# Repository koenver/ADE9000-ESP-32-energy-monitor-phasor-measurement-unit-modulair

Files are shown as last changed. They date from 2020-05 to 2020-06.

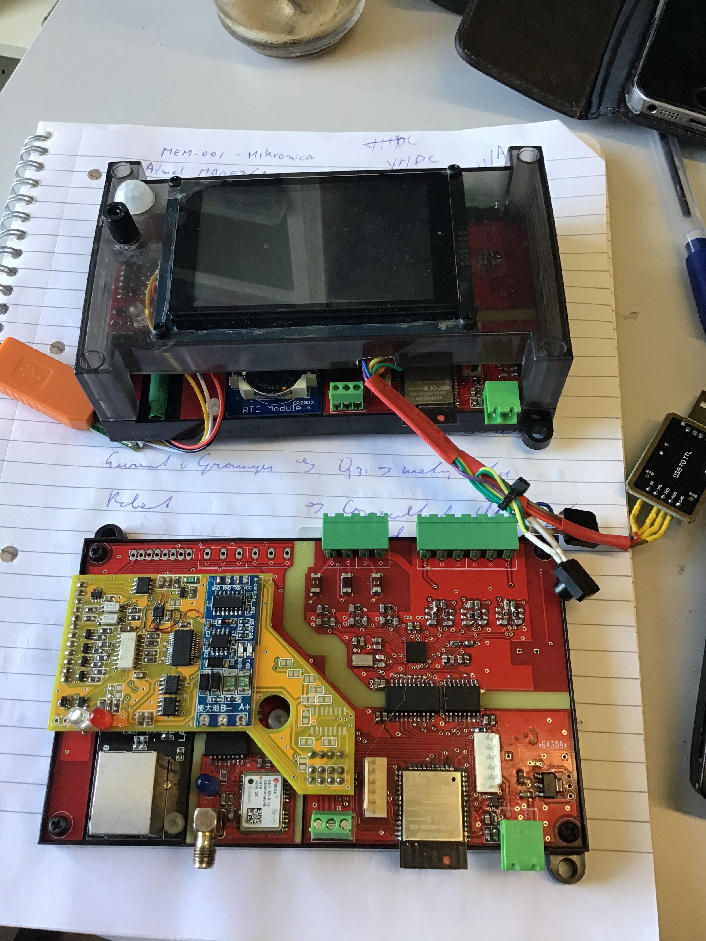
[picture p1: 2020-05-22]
hardware/pictures/IMG_0286.jpg

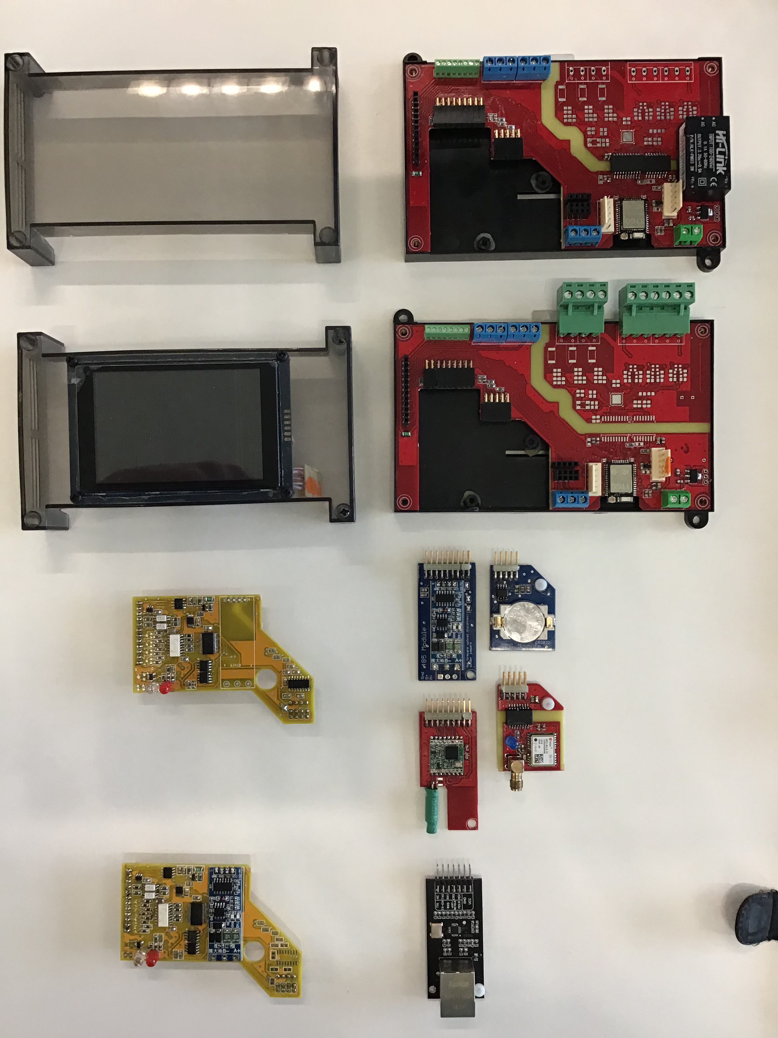
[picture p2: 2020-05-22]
hardware/pictures/IMG_0275.jpg

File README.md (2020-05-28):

# **ADE9000 ESP-32 energy-monitor / phasor-measurement-unit modulair**<br/>

*Prototype version of an Energy Measurement / Phasor Measurement unit with modulair interface modules*<br/>

**Specs:**<br/>
* ESP-32 processor (with double SPI and multicore, multi-tasking) and Wifi<br/> 
* Galvanic seperation with ADUM chips <br/>
* ADE9000 3 phase Energy Measurement IC , version for CT (5VA) or <br/>
        rogowski (0.1mV/A), 8kHz wavebuffering , harmonics analyses and <br/>
        event processing for 50Hz , 230V 3 phase Energy systems <br/>
* Module 1 slot: 485 interface / lorawan 868 Mhz/ Ethernet lan8720 (waveshare)<br/>
        
* Module 2 slot: Ublox GPS / DS3232 RTC<br/> 
* Expansion board: 485 interface, 2x 24lc512, mcp23017, ds2482, mcp4725,BME680<br/> 
        so 4 DI (opto), 4 DO (opto), 1-wire , temp, humidity, voc, air-pressure, <br/>
	AD en DA inputs and extra flash <br/>
* Optional I2C display  (SED1306 or H35B-I)<br/>
* future development:  security TLS1.3, module 2 with NB-Iot-LTE-M (Ublox)<br/> 
* Arduino IDE , in RTOS , C++ Language <br/>
<br/>

#### *Now in testing phase -> so only use parts which I confirmed status tested*<br/>
#### *better wait till new PCB's are published, instead of using the manual re-wiring*<br/>
*Software will be open source. (New) soft- and hardware which is based on this*<br/> 
*project and used by others, have the obligation of open source publishing*<br/> 
*at Github*<br/>

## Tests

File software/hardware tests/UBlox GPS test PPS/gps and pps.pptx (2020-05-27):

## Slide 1

PPS pulse of GPS: duration 100ms

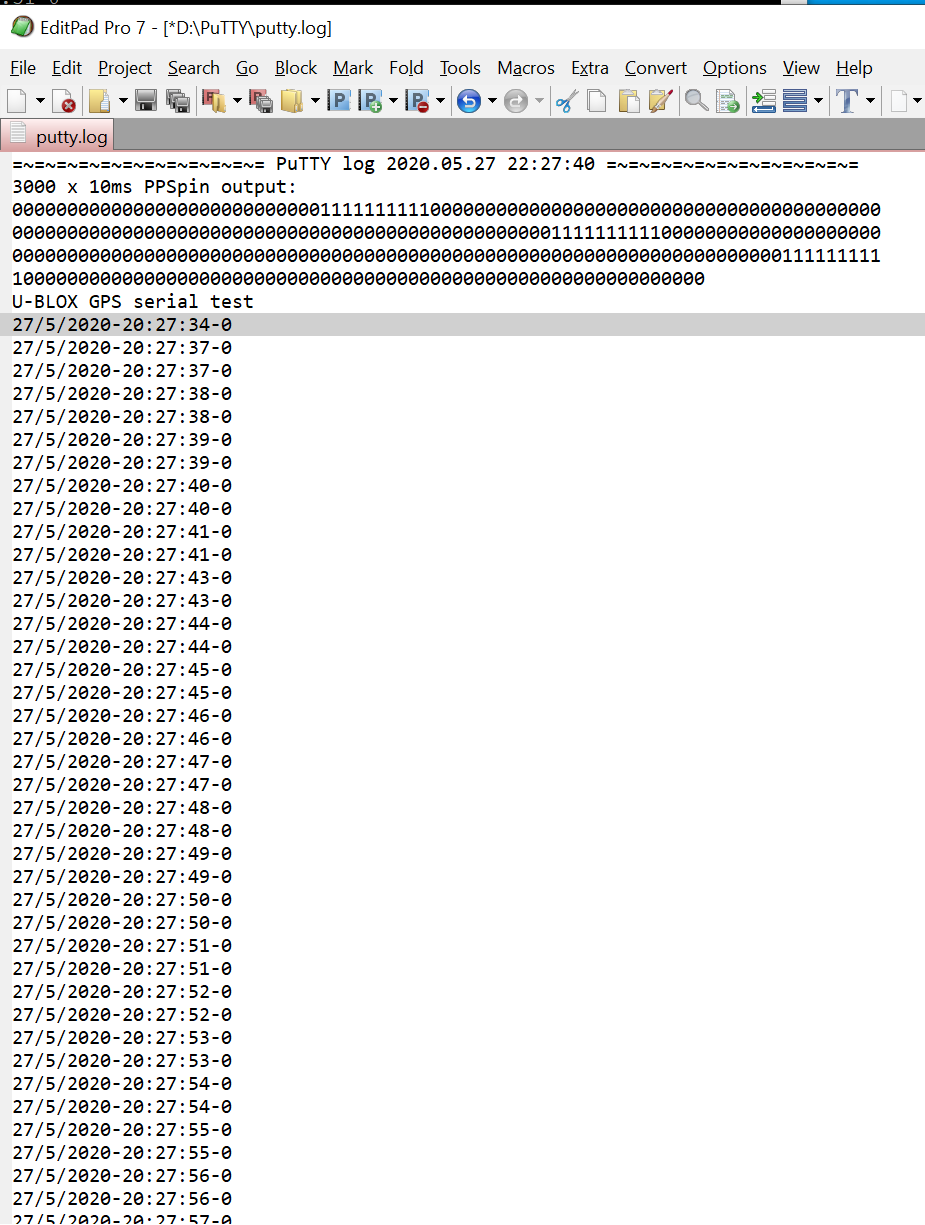
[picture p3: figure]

PPS of 100ms
is seen 10x10ms

Modification PCB :
gpio 9 and 10
aren’t free with DIO..
So Tx-GPS was placed at ESP-RX1 …GPS module needs to be removed before programming! ESP-TX was used for terminal debug (9600baud)
This gives the repeating error:
(putty at Tx and GPS at Rx)

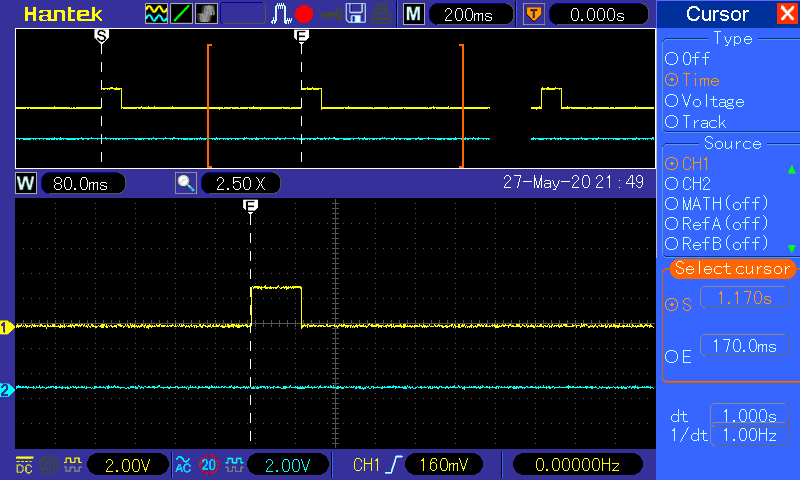
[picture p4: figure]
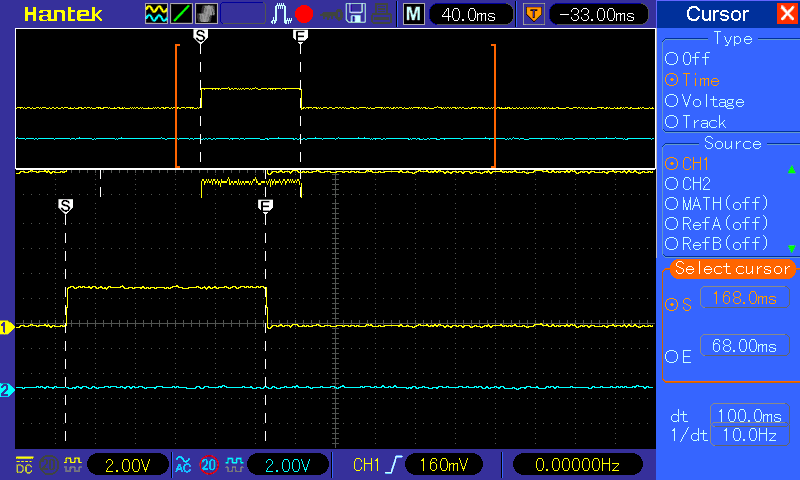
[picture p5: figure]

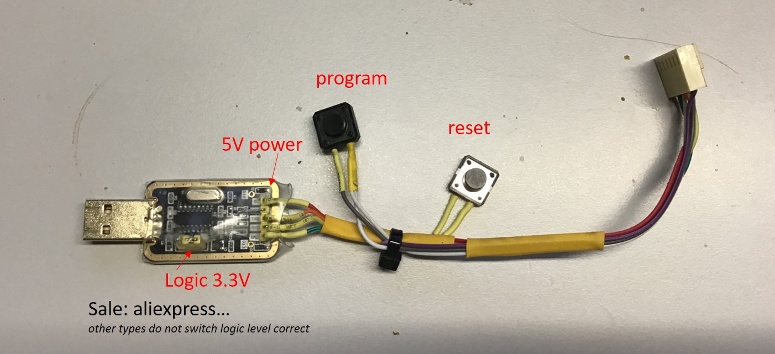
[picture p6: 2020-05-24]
software/hardware tests/programmer/programmer.jpg

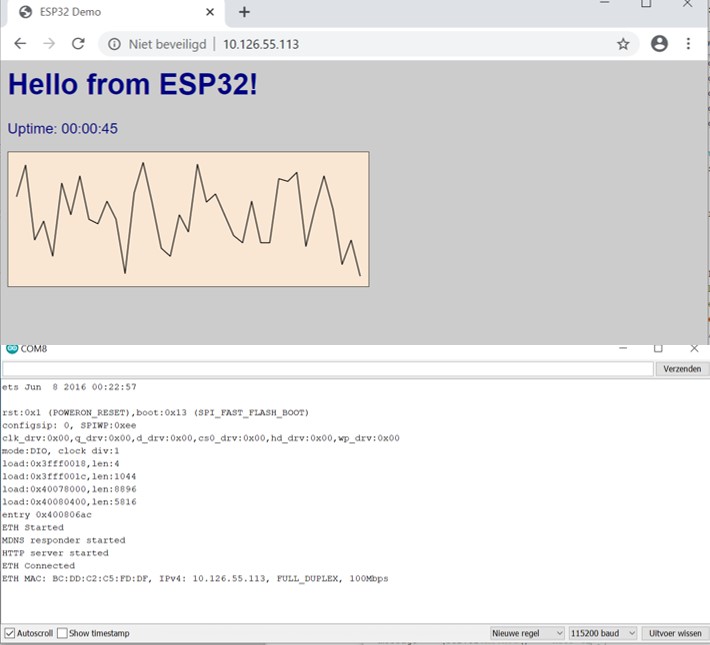
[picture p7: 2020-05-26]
software/hardware tests/lan8720 test/servertest-OK/ETH_LAN8720webserver-output.jpg

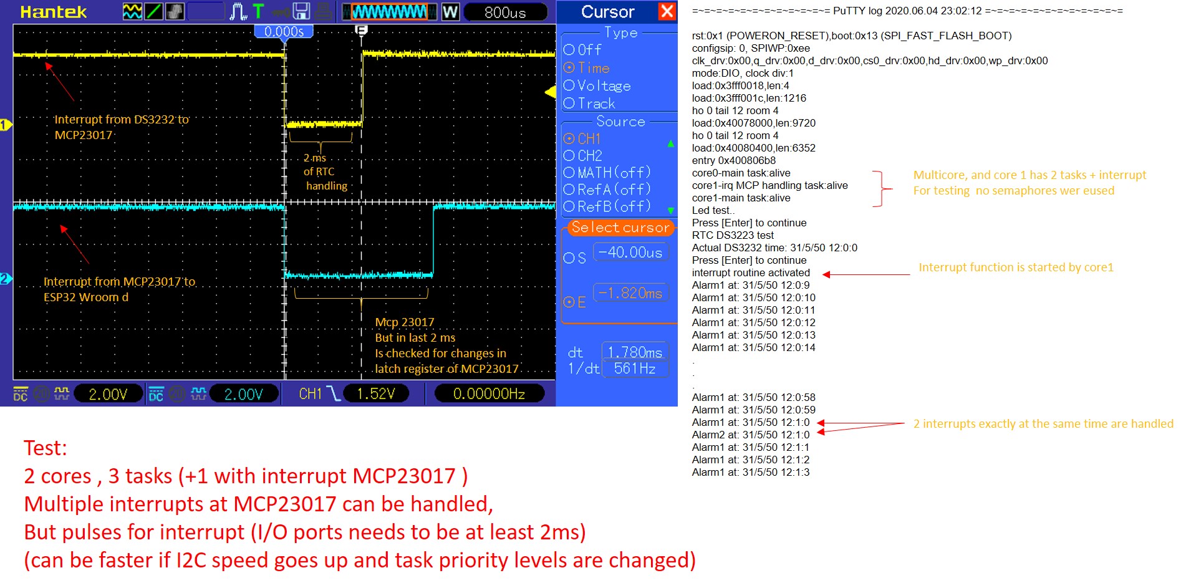
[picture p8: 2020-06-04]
software/hardware tests/MCP23017-IRQ-mCore-DS3232 test/MCP-multicore -interrupt.jpg

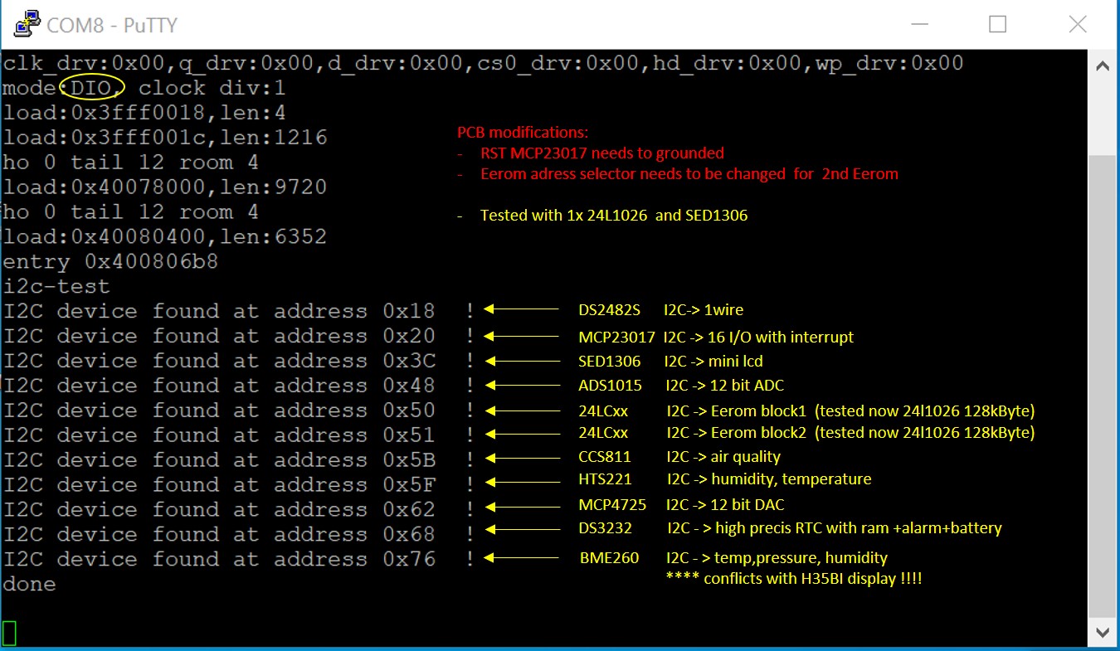
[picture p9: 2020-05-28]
software/hardware tests/i2c test/I2C adres dump1.jpg

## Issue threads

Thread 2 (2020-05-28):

RST of MCP23107 needs to be grounded (expansion board)

koenver, 2020-05-28:
resolved temp:  little wire soldered

koenver, 2020-06-04:
sorry..my mistake ..is an  "/RST"  so must be wired to 3.3V

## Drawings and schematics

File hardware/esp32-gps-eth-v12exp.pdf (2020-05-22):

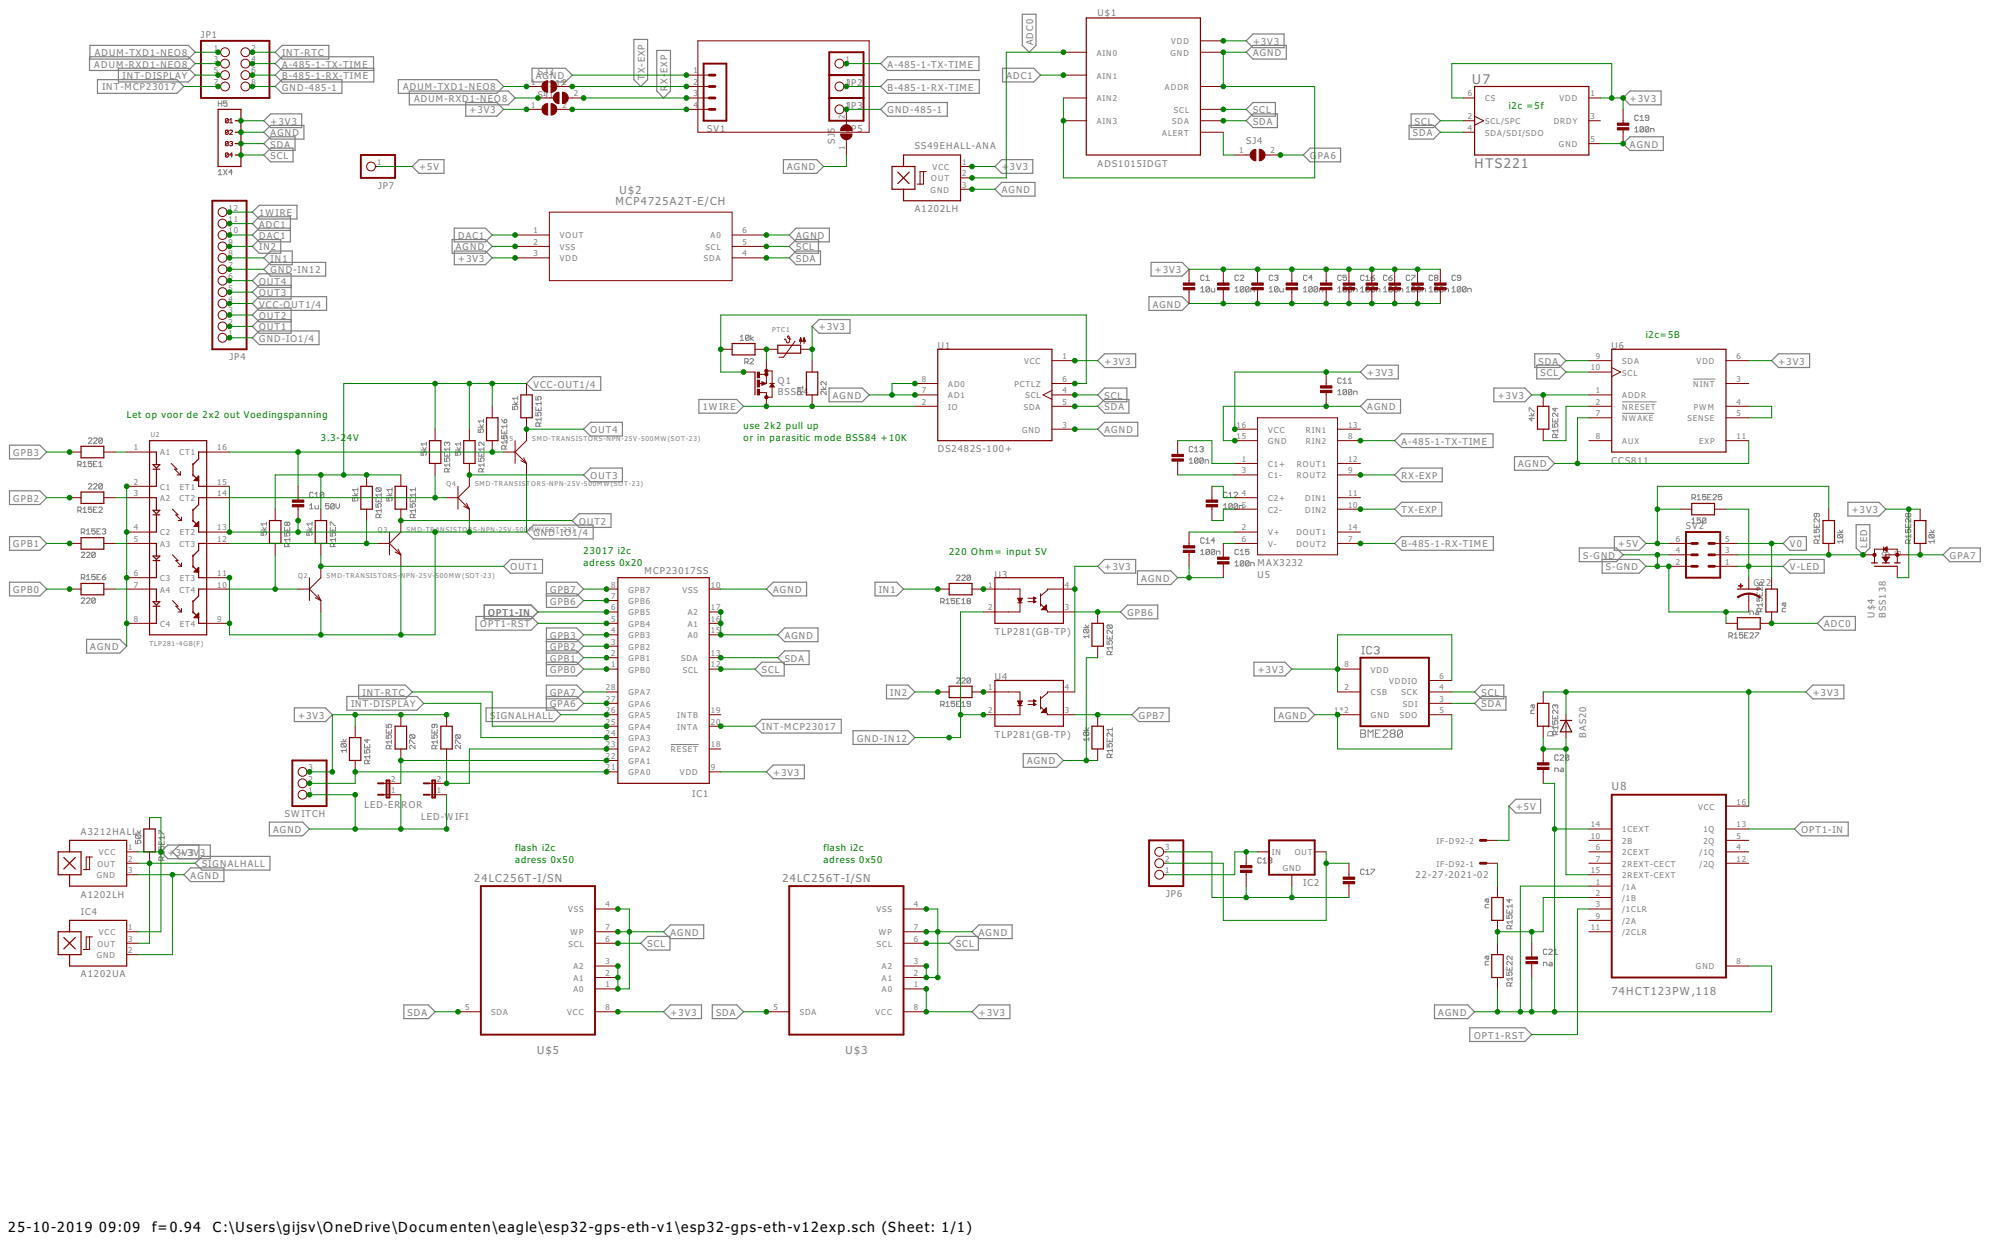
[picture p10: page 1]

Let op voor de 2x2 out Voedingspanning

SMD-TRANSISTORS-NPN-25V-500MW (SOT-23)

25-10-2019 09:09 f=0.94 C:\Users\gijsv\OneDrive\Documenten\eagle\esp32-gps-eth-v1\esp32-gps-eth-v12exp.sch (Sheet: 1/1)

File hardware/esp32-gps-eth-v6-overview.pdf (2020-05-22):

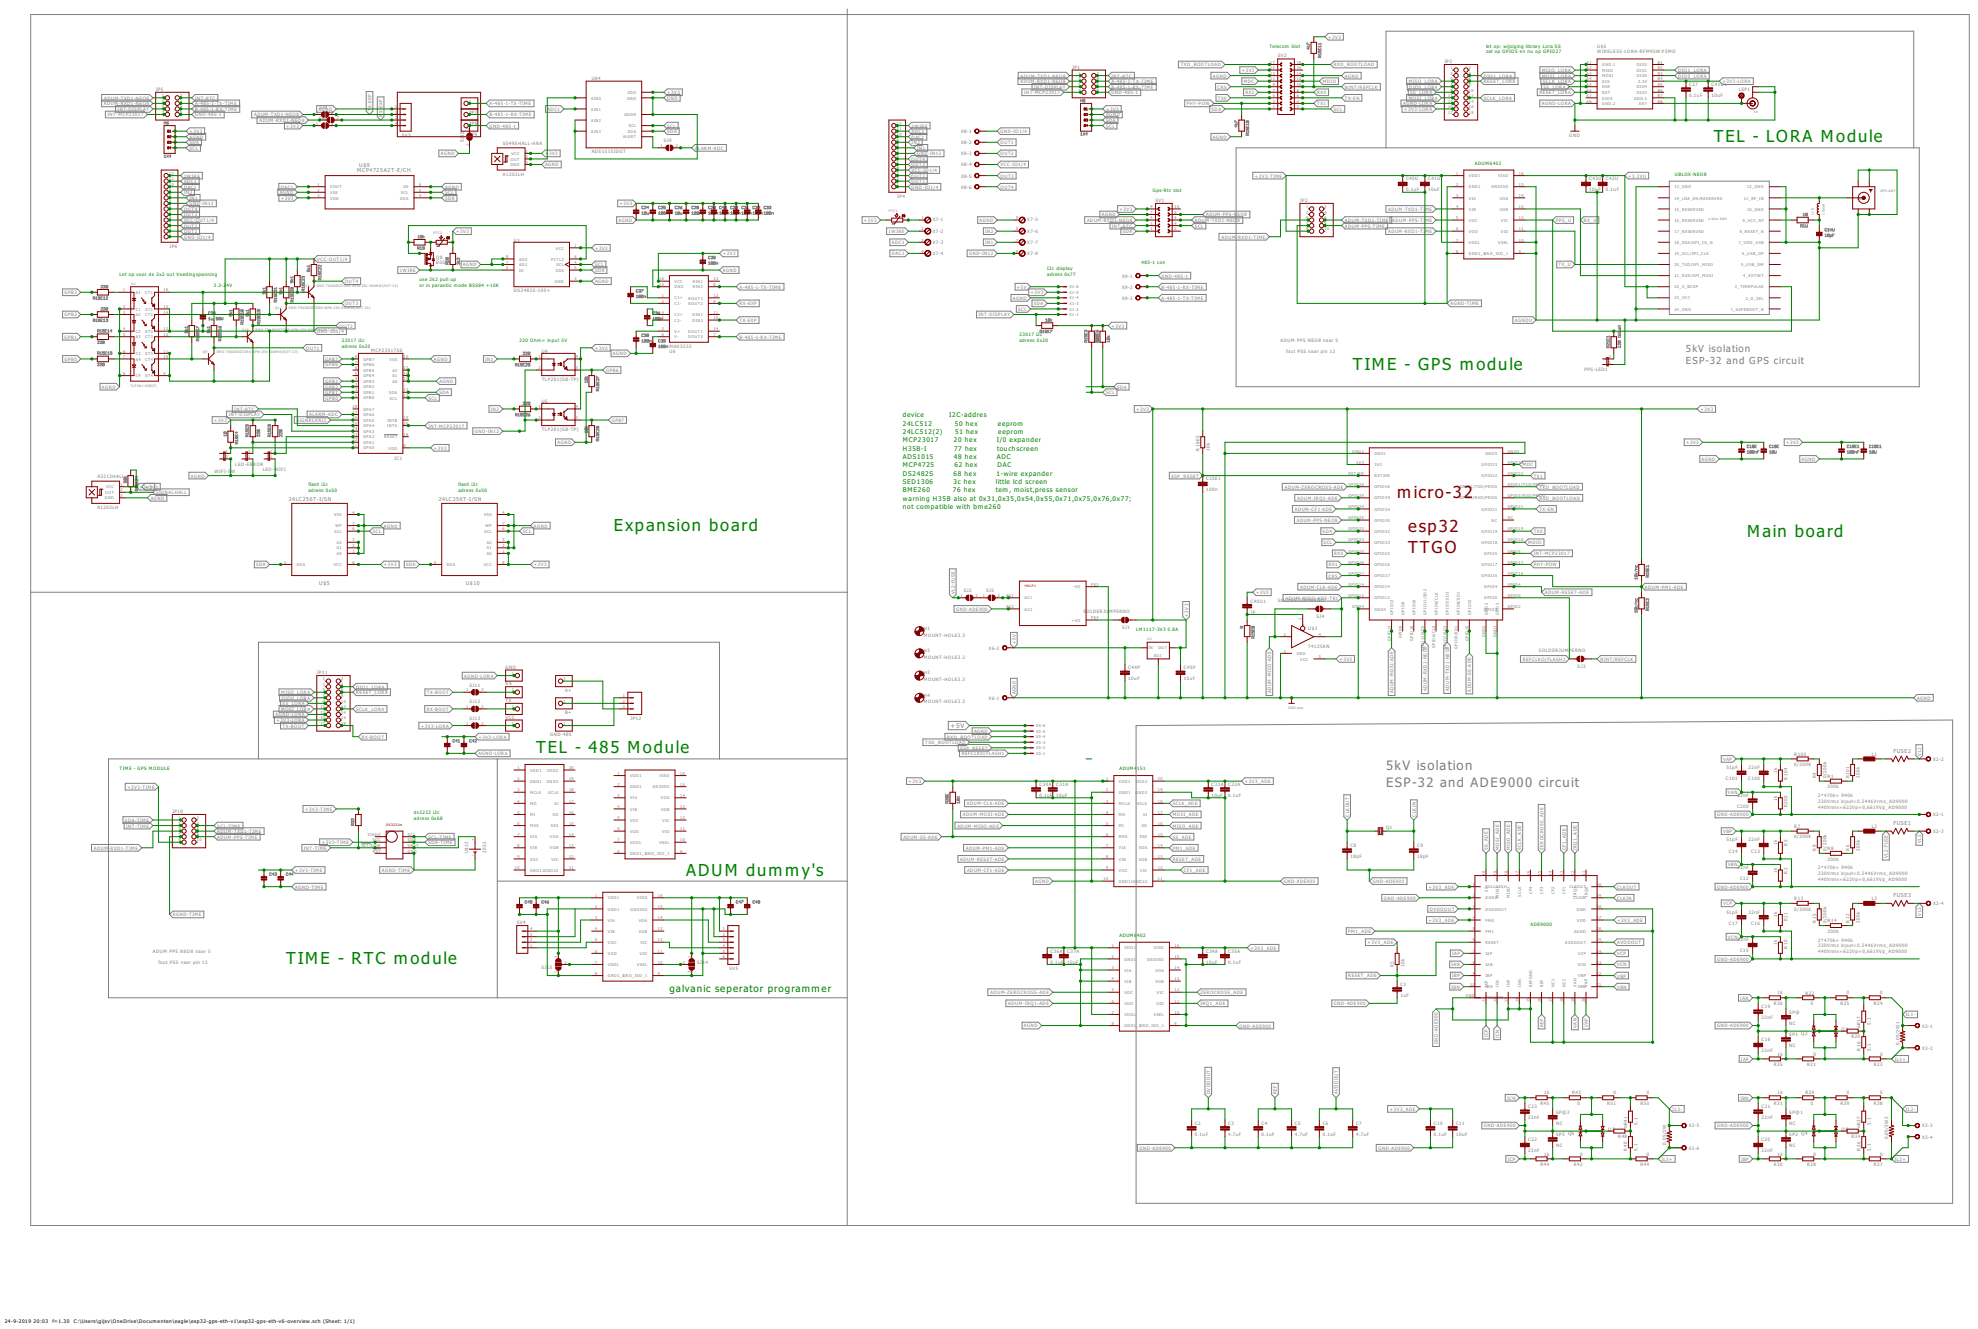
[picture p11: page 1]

let op: wijziging library Lora SS
zat op GPIO5 en nu op GPIO27

Let op voor de 2x2 out Voedingspanning

SMD-TRANSISTORS-NPN-25V-500MW (SOT-23)

5kV isolation
ESP-32 and GPS circuit

fout PSS naar pin 12

Main board Expansion board

ADUM-MISO-ADE-TRI
SOLDERJUMPERNO

SpiceOrder 1 SpiceOrder 2

24-9-2019 20:03 f=1.30 C:\Users\gijsv\OneDrive\Documenten\eagle\esp32-gps-eth-v1\esp32-gps-eth-v6-overview.sch (Sheet: 1/1)

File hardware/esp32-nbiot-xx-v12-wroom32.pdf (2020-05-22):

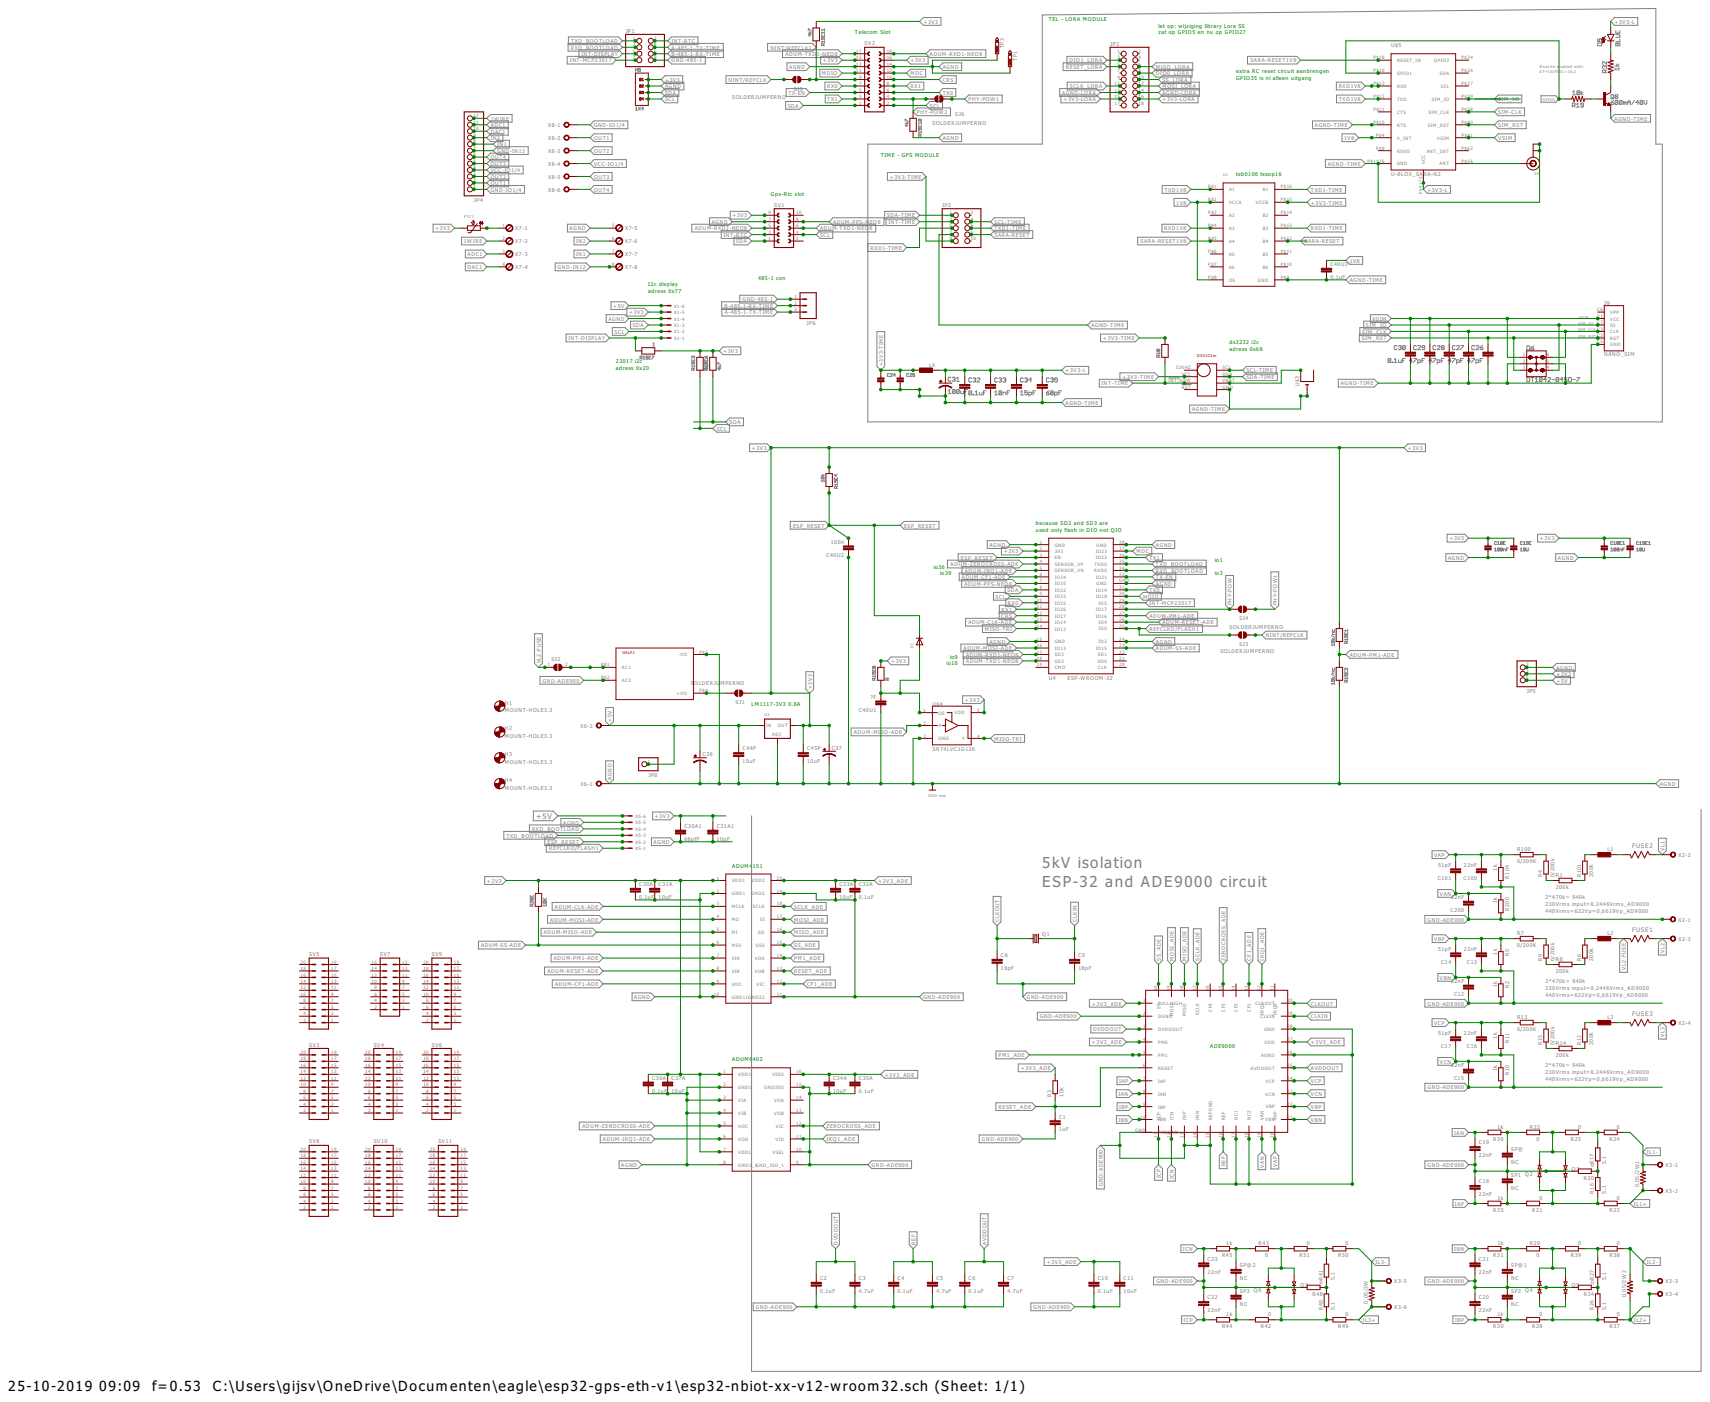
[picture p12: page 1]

zat op GPIO5 en nu op GPIO27 TEL - LORA MODULE

let op: wijziging library Lora SS

extra RC reset circuit aanbrengen GPIO35 is nl alleen uitgang

Must be enabled with: AT+UGPIOC=16,2

AGND-TIME AGND-TIME AGND-TIME

because SD2 and SD3 are used only flash in DIO not QIO

MOUNT-HOLE3.3 MOUNT-HOLE3.3

Sp ic eOrd er 1 Sp ic eOrd er 2

25-10-2019 09:09 f=0.53 C:\Users\gijsv\OneDrive\Documenten\eagle\esp32-gps-eth-v1\esp32-nbiot-xx-v12-wroom32.sch (Sheet: 1/1)

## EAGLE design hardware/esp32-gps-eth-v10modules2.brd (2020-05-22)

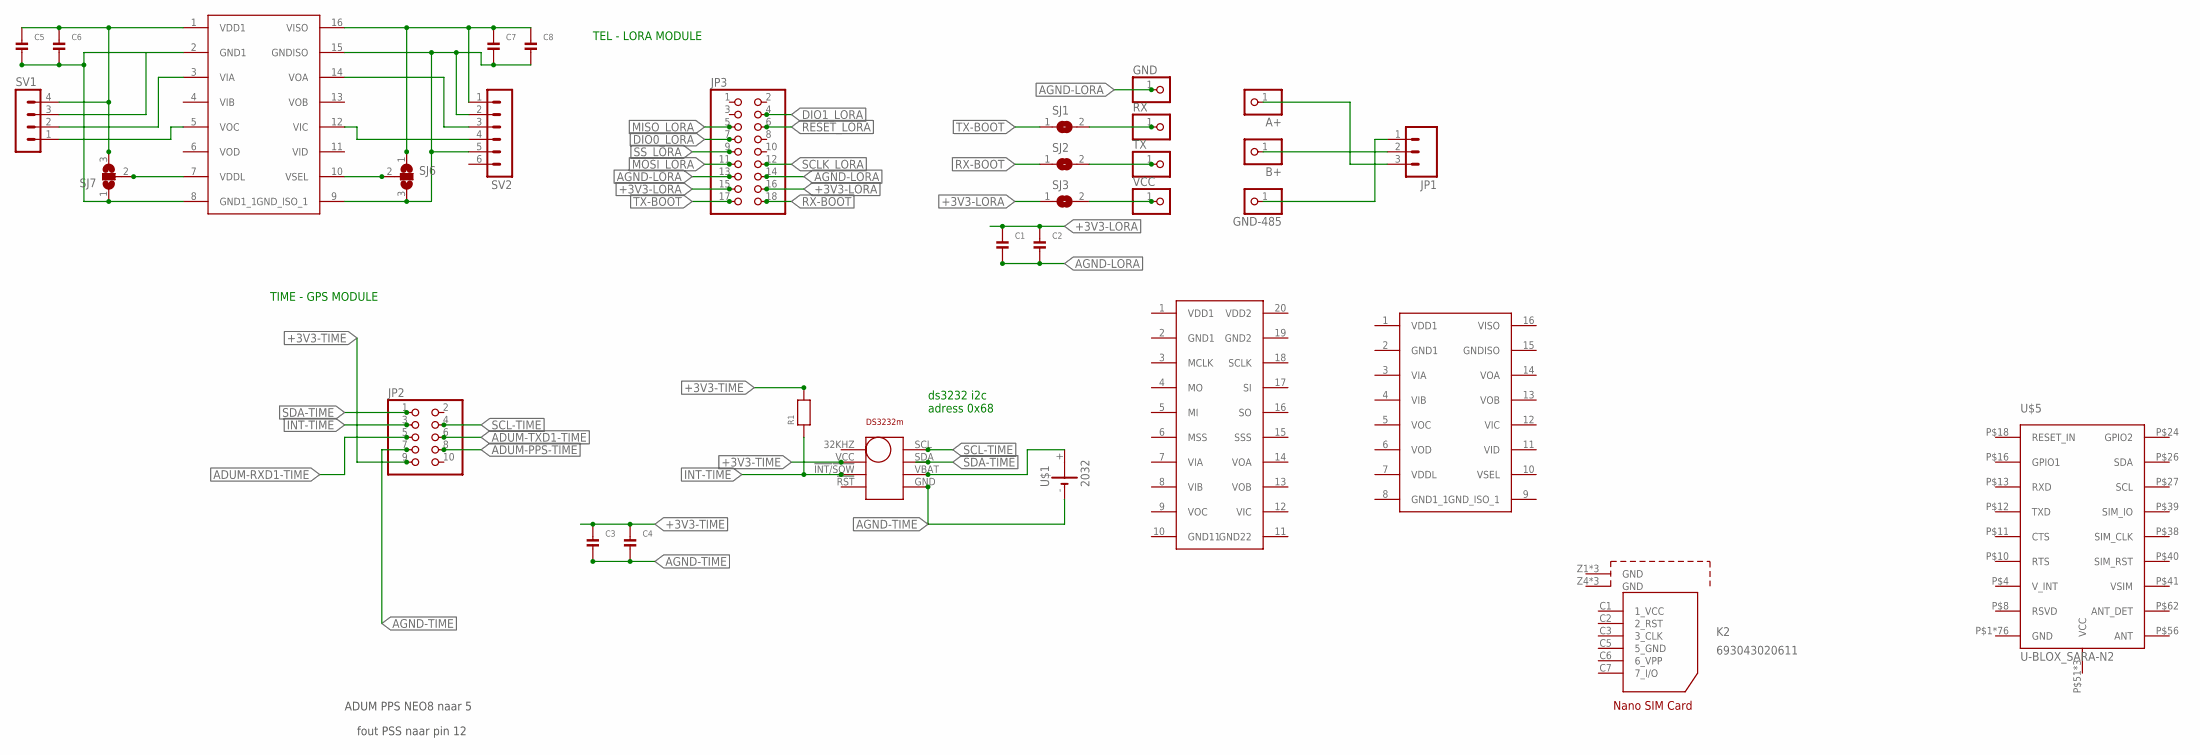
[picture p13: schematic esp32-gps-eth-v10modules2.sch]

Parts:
A+: PINHD-1X1CB; 1X01-CLEANBIG
ADUM4151: ADUM4151; SOIC20R
B+: PINHD-1X1CB; 1X01-CLEANBIG
C1, C2, C3, C4, C5, C6, C7, C8: CAP_CERAMIC0805; 0805
GND: PINHD-1X1CB; 1X01-CLEANBIG
GND-485: PINHD-1X1CB; 1X01-CLEANBIG
JP1: M03SCREW; SCREWTERMINAL-3.5MM-3
JP2: PINHD-2X5/90; 2X05/90
JP3: PINHD-2X9/90; 2X09/90
K2: 693043020611
R1: RESISTOR0805; 0805
RX: PINHD-1X1CB; 1X01-CLEANBIG
SJ1, SJ2, SJ3: SOLDERJUMPERREFLOW; SOLDERJUMPER_REFLOW
SJ6, SJ7: SJ2W; SJ_2
SV1: MA04-1
SV2: MA06-1
TX: PINHD-1X1CB; 1X01-CLEANBIG
U$1: 2032; KZH20SMD
U$2, U$3: ADUM6402; SOIC16R
U$4: DS3232M; SOIC8
U$5: U-BLOX_SARA-N2; SARA-N2
VCC: PINHD-1X1CB; 1X01-CLEANBIG

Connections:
+3V3-LORA: C1.1, C2.1, JP3.15, JP3.16, SJ3.1
+3V3-TIME: C3.1, C4.1, JP2.9, R1.2, U$4.VCC
ADUM-PPS-TIME: JP2.8
ADUM-RXD1-TIME: JP2.5
ADUM-TXD1-TIME: JP2.6
AGND-LORA: C1.2, C2.2, GND.1, JP3.13, JP3.14
AGND-TIME: C3.2, C4.2, JP2.7, U$1.-, U$4.GND
DIO0_LORA: JP3.7
DIO1_LORA: JP3.4
GND: U$5.P$1 (GND), U$5.P$2 (GND), U$5.P$3 (GND), U$5.P$5 (GND), U$5.P$6 (GND), U$5.P$7 (GND), U$5.P$9 (GND), U$5.P$14 (GND), U$5.P$15 (GND), U$5.P$17 (GND), U$5.P$19 (GND), U$5.P$20 (GND), U$5.P$21 (GND), U$5.P$22 (GND), U$5.P$23 (GND), U$5.P$25 (GND), U$5.P$28 (GND), U$5.P$29 (GND), U$5.P$30 (GND), U$5.P$31 (GND), U$5.P$32 (GND), U$5.P$33 (GND), U$5.P$34 (GND), U$5.P$35 (GND), U$5.P$36 (GND), U$5.P$37 (GND), U$5.P$42 (GND), U$5.P$43 (GND), U$5.P$44 (GND), U$5.P$45 (GND), U$5.P$46 (GND), U$5.P$47 (GND), U$5.P$48 (GND), U$5.P$49 (GND), U$5.P$50 (GND), U$5.P$54 (GND), U$5.P$55 (GND), U$5.P$57 (GND), U$5.P$58 (GND), U$5.P$59 (GND), U$5.P$60 (GND), U$5.P$61 (GND), U$5.P$63 (GND), U$5.P$64 (GND), U$5.P$65 (GND), U$5.P$66 (GND), U$5.P$67 (GND), U$5.P$68 (GND), U$5.P$69 (GND), U$5.P$70 (GND), U$5.P$71 (GND), U$5.P$72 (GND), U$5.P$73 (GND), U$5.P$74 (GND), U$5.P$75 (GND), U$5.P$76 (GND), U$5.P$77 (GND), U$5.P$78 (GND), U$5.P$79 (GND), U$5.P$80 (GND), U$5.P$81 (GND), U$5.P$82 (GND), U$5.P$83 (GND), U$5.P$84 (GND), U$5.P$85 (GND), U$5.P$86 (GND), U$5.P$87 (GND), U$5.P$88 (GND), U$5.P$89 (GND), U$5.P$90 (GND), U$5.P$91 (GND), U$5.P$92 (GND), U$5.P$93 (GND), U$5.P$94 (GND), U$5.P$95 (GND), U$5.P$96 (GND)
GND-PROG1: C5.2, C6.2, SJ7.1, U$3.8 (GND1_1)
GND-PROG2: C7.2, C8.2, SJ6.3, SV2.2, SV2.5, U$3.9 (GND_ISO_1), U$3.15 (GNDISO)
INT-TIME: JP2.3, R1.1, U$4.!INT/!!SQW
MISO_LORA: JP3.5
MOSI_LORA: JP3.11
unnamed: A+.1, JP1.3
unnamed: B+.1, JP1.2
unnamed: GND-485.1, JP1.1
unnamed: RX.1, SJ1.2
unnamed: U$1.+, U$4.VBAT
unnamed: SJ2.2, TX.1
unnamed: SJ3.2, VCC.1
unnamed: SV1.1, U$3.5 (VOC)
unnamed: SV1.3, U$3.2 (GND1)
unnamed: SV1.2, U$3.3 (VIA)
unnamed: SV2.3, U$3.14 (VOA)
unnamed: SV2.4, U$3.12 (VIC)
unnamed: SJ7.2, U$3.7 (VDDL)
unnamed: SJ6.2, U$3.10 (VSEL)
RESET_LORA: JP3.6
RX-BOOT: JP3.18, SJ2.1
SCL-TIME: JP2.4, U$4.SCL
SCLK_LORA: JP3.12
SDA-TIME: JP2.1, U$4.SDA
SS_LORA: JP3.9
TX-BOOT: JP3.17, SJ1.1
VCC: U$5.P$51 (VCC), U$5.P$52 (VCC), U$5.P$53 (VCC)
VCC2-PROG: C7.1, C8.1, SJ6.1, SV2.1, U$3.16 (VISO)
VCC-PROG: C5.1, C6.1, SJ7.3, SV1.4, U$3.1 (VDD1)

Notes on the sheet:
ADUM PPS NEO8 naar 5
fout PSS naar pin 12
ds3232 i2c adress 0x68
TEL - LORA MODULE
TIME - GPS MODULE

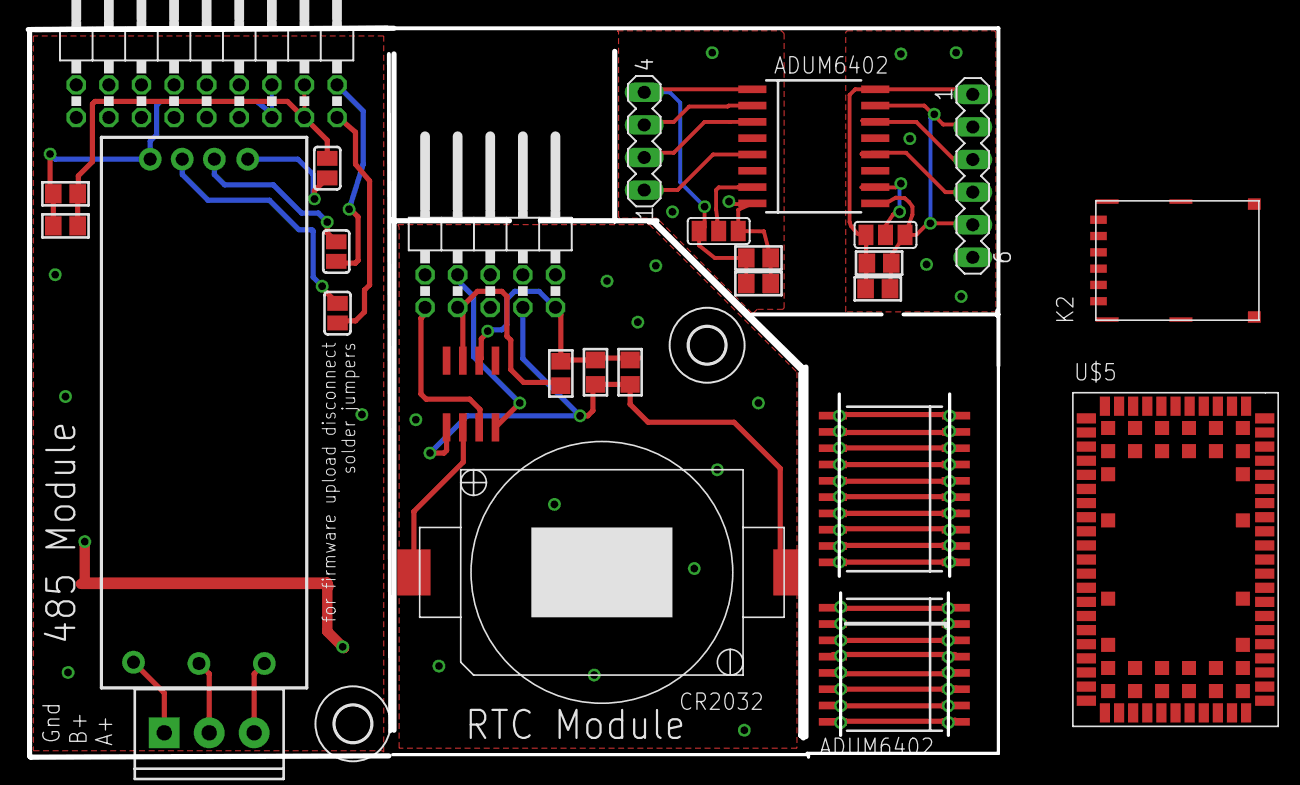
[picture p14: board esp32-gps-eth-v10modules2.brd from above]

Board: 2 copper layers, 75.6 x 56.8 mm, 35 parts (0 on the bottom side), 29 nets.

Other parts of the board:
U$7, U$8: 2,8

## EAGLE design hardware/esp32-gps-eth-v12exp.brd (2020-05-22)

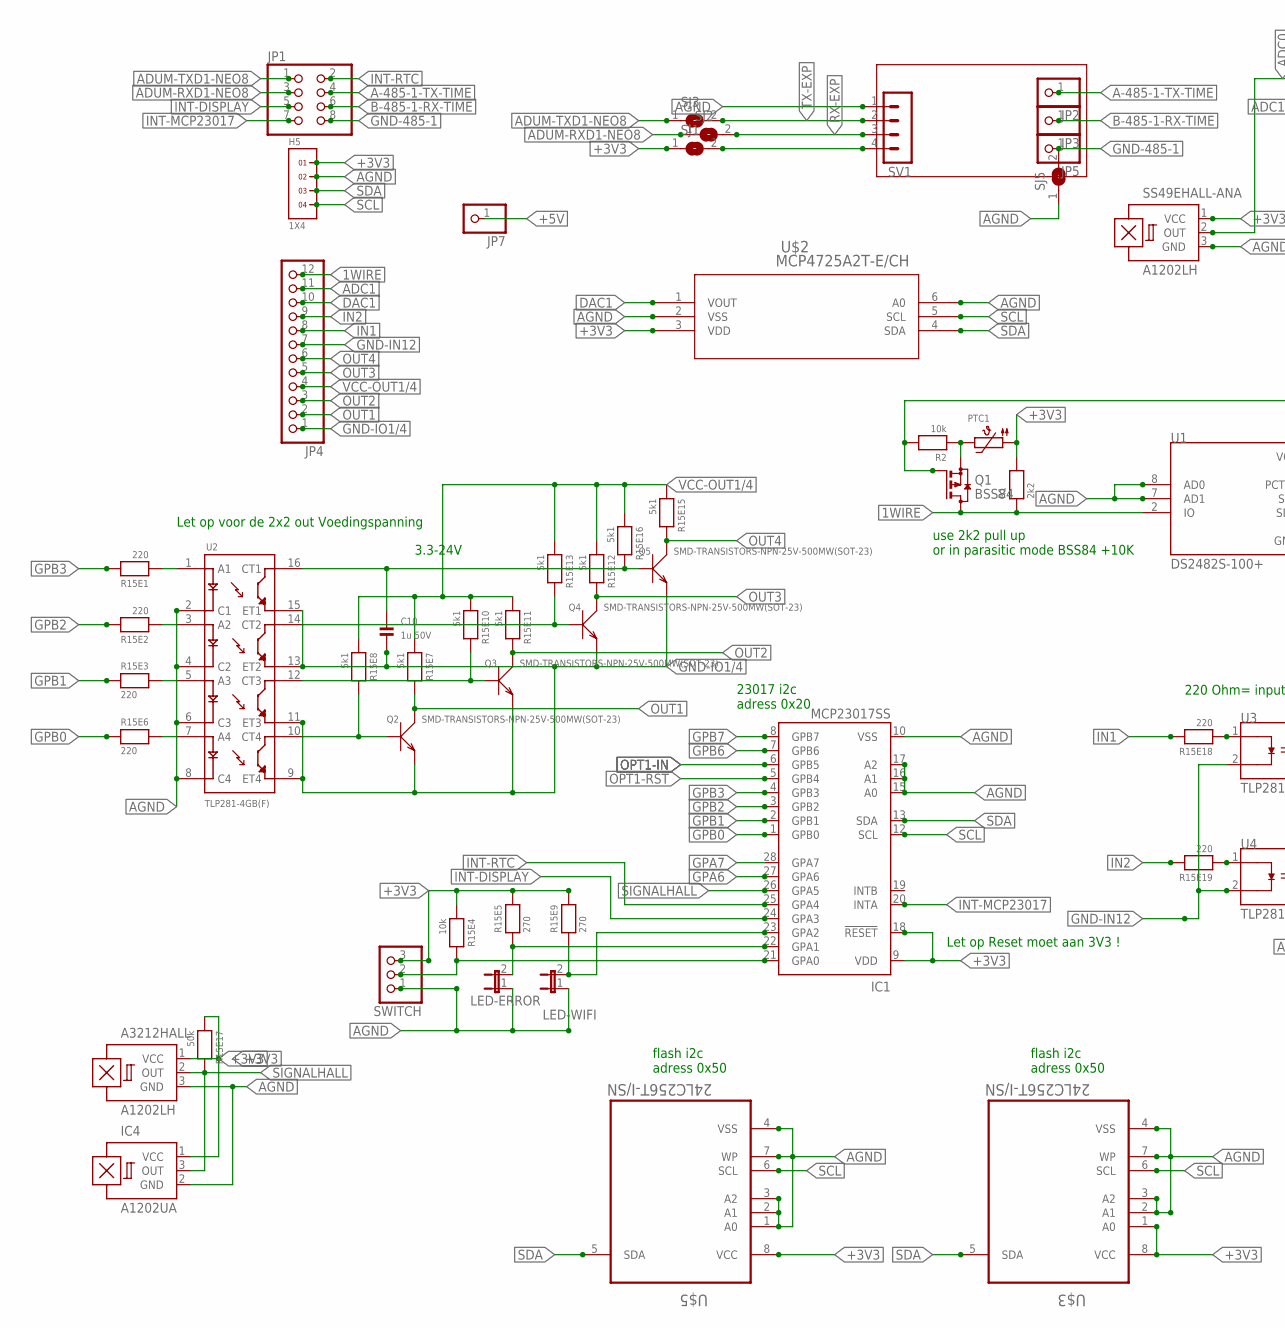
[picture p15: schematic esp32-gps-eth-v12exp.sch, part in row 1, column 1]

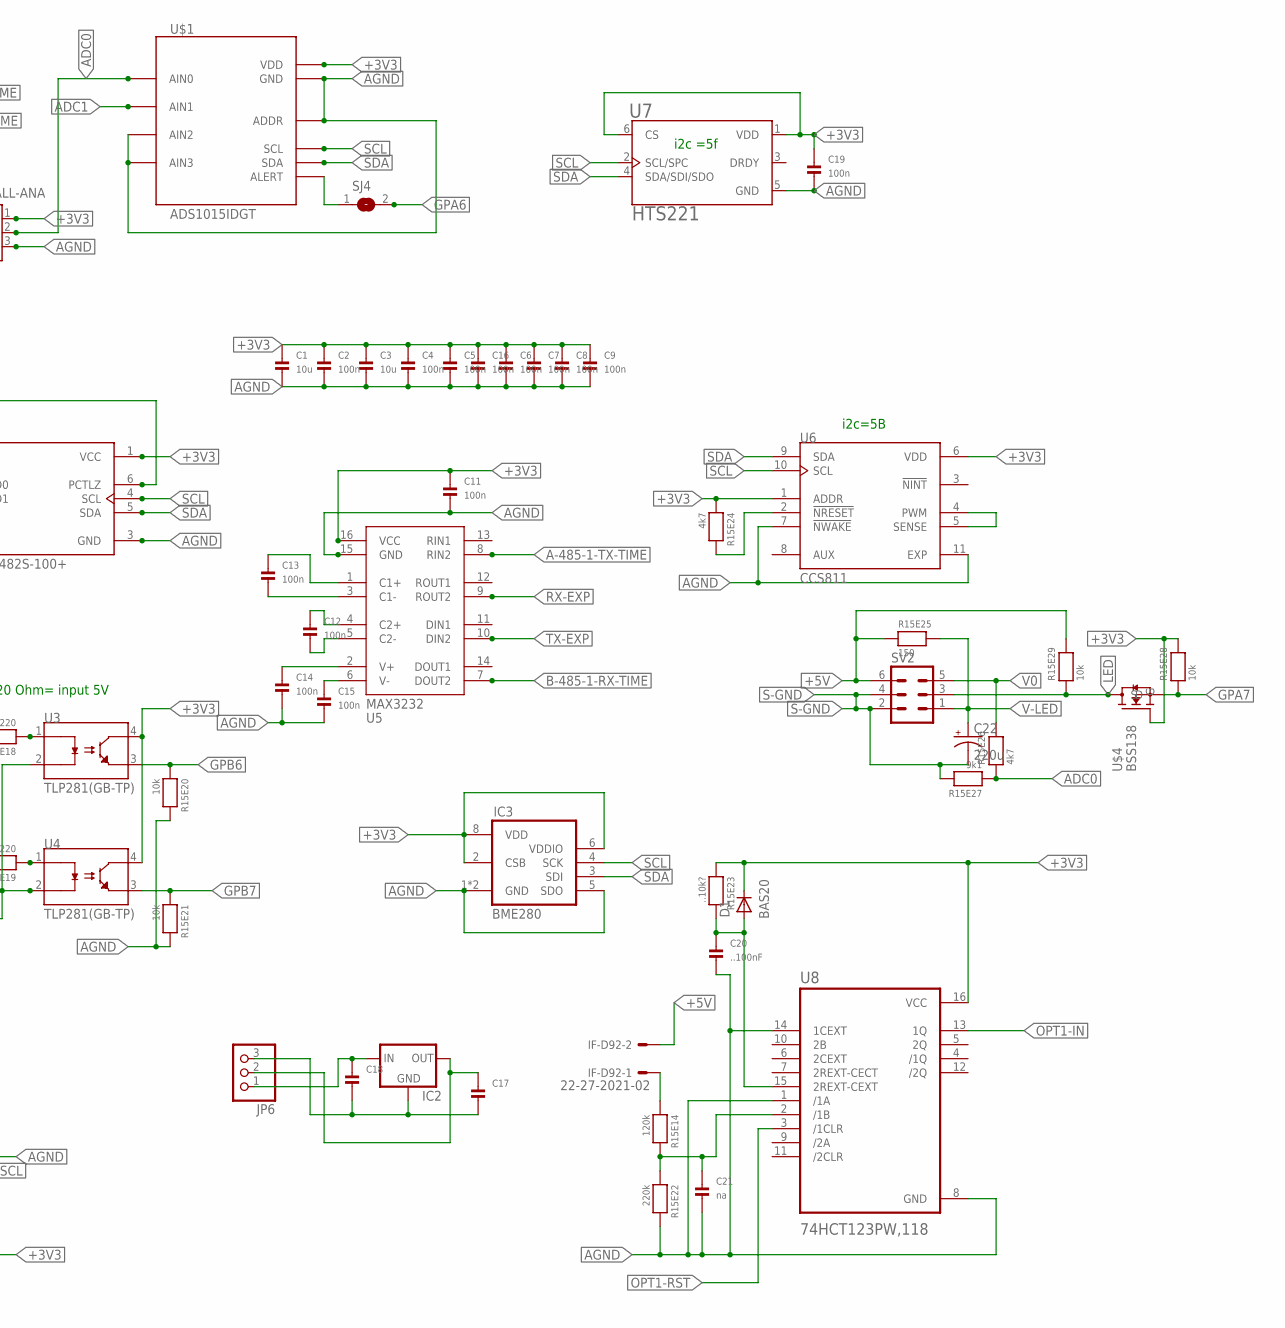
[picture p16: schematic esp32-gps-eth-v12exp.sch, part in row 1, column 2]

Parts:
A3212HALL: A1202LH; SOT23-W
C1, C3: 10u; 0805
C2, C4, C5, C6, C7, C8, C9, C11, C12, C13, C14, C15, C16, C19: 100n; 0805
C10: 1u 50V; 0805
C17, C18: CAP_CERAMIC0805; 0805
C20: ..100nF; 0805
C21: na; 0805
C22: 220u; 153CLV-0605
D1: BAS20; SOT23
H5: 1X4
IC1: MCP23017SS; SSOP28
IC2: LM1117TO263; TO263
IC3: BME280
IC4: A1202UA; SIP3-UA
IF-D92: 22-27-2021-02; 6410-02
JP1: PINHD-2X4; 2X04
JP2, JP3, JP5, JP7: PINHD-1X1; 1X01
JP4: PINHD-1X12; 1X12
JP6: PINHD-1X3; 1X03
LED-ERROR: JP1E; JP1
LED-WIFI: JP1E; JP1
PTC1: PTC1206; 1206
Q1: BSS84; SOT23
Q2, Q3, Q4, Q5: SMD-TRANSISTORS-NPN-25V-500MW(SOT-23); SOT-23
R1: 2k2; 0805
R2: 10k; 0805
R15E1, R15E2, R15E3, R15E6, R15E18, R15E19: 220; _0805
R15E4, R15E20, R15E21, R15E28, R15E29: 10k; _0805
R15E5, R15E9: 270; _0805
R15E7, R15E8, R15E10, R15E11, R15E12, R15E13, R15E15, R15E16: 5k1; _0805
R15E14: 120k; _0805
R15E17: 50k; _0805
R15E22: 220k; _0805
R15E23: ..10k?; _0805
R15E24, R15E26: 4k7; _0805
R15E25: 150; _0805
R15E27: 9k1; _0805
SJ1, SJ2, SJ3, SJ4, SJ5: SJ
SS49EHALL-ANA: A1202LH; SOT23-W
SV1: MA04-1
SV2: MA03-2
SWITCH: PINHD-1X3; 1X03
U1: DS2482S-100+; SOIC127P600X175-8N
U2: TLP281-4GB(F); SOIC127P700X210-16N
U3, U4: TLP281(GB-TP); SOIC127P700X210-4N
U5: MAX3232; SO16
U6: CCS811; SON60P270X400X110-11N
U7: HTS221; XDCR_HTS221
U8: 74HCT123PW,118; SOP65P640X110-16N
U$1: ADS1015IDGT; MSOP10_0.5
U$2: MCP4725A2T-E/CH; SOT-23-6_MC
U$3, U$5: 24LC256T-I/SN; SOIC127P600X175-8N
U$4: BSS138

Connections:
1WIRE: JP4.12, Q1.3 (D), R1.1, U1.2 (IO)
5VIN: C18.1, IC2.3 (IN), JP6.1
+3V3: A3212HALL.1 (VCC), C1.1, C2.1, C3.1, C4.1, C5.1, C6.1, C7.1, C8.1, C9.1, C11.1, C16.1, C19.1, D1.3 (K), H5.1, IC1.9 (VDD), IC1.18 (!RESET), IC3.2 (CSB), IC3.6 (VDDIO), IC3.8 (VDD), IC4.1 (VCC), PTC1.1, R1.2, R15E4.1, R15E5.2, R15E9.2, R15E17.1, R15E23.1, R15E24.1, R15E28.2, SJ1.1, SS49EHALL-ANA.1 (VCC), SWITCH.3, U1.1 (VCC), U3.4 (COLLECTOR), U4.4 (COLLECTOR), U5.16 (VCC), U6.1 (ADDR), U6.6 (VDD), U7.1 (VDD), U7.6 (CS), U8.16 (VCC), U$1.8 (VDD), U$2.3 (VDD), U$3.1 (A0), U$3.8 (VCC), U$4.G, U$5.8 (VCC)
+5V: IF-D92.2, JP7.1, R15E25.1, R15E29.2, SV2.6
A-485-1-TX-TIME: JP1.4, JP2.1, U5.8 (RIN2)
ADC0: R15E26.1, R15E27.1, SS49EHALL-ANA.2 (OUT), U$1.4 (AIN0)
ADC1: JP4.11, U$1.5 (AIN1)
ADUM-RXD1-NEO8: JP1.3, SJ2.1
ADUM-TXD1-NEO8: JP1.1, SJ3.1
AGND: A3212HALL.3 (GND), C1.2, C2.2, C3.2, C4.2, C5.2, C6.2, C7.2, C8.2, C9.2, C11.2, C14.2, C15.2, C16.2, C19.2, C20.2, C21.2, H5.2, IC1.10 (VSS), IC1.15 (A0), IC1.16 (A1), IC1.17 (A2), IC3.1 (GND), IC3.5 (SDO), IC3.7 (GND), IC4.2 (GND), LED-ERROR.1, LED-WIFI.1, R15E20.2, R15E21.2, R15E22.2, SJ5.1, SS49EHALL-ANA.3 (GND), SV1.1, SWITCH.1, U1.3 (GND), U1.7 (AD1), U1.8 (AD0), U2.2 (C1), U2.4 (C2), U2.6 (C3), U2.8 (C4), U5.15 (GND), U6.7 (!NWAKE), U6.11 (EXP), U7.5 (GND), U8.1 (/1A), U8.8 (GND), U8.14 (1CEXT), U$1.1 (ADDR), U$1.3 (GND), U$1.6 (AIN2), U$1.7 (AIN3), U$2.2 (VSS), U$2.6 (A0), U$3.2 (A1), U$3.3 (A2), U$3.4 (VSS), U$3.7 (WP), U$5.1 (A0), U$5.2 (A1), U$5.3 (A2), U$5.4 (VSS), U$5.7 (WP)
B-485-1-RX-TIME: JP1.6, JP3.1, U5.7 (DOUT2)
DAC1: JP4.10, U$2.1 (VOUT)
GND-485-1: JP1.8, JP5.1, SJ5.2
GND-IN: C17.2, C18.2, IC2.1 (GND), JP6.3
GND-IN12: JP4.7, U3.2 (CATHODE), U4.2 (CATHODE)
GND-IO1/4: C10.2, JP4.1, Q2.2 (E), Q3.2 (E), Q4.2 (E), Q5.2 (E), U2.9 (ET4), U2.11 (ET3), U2.13 (ET2), U2.15 (ET1)
GPA6: IC1.27 (GPA6), SJ4.2
GPA7: IC1.28 (GPA7), R15E28.1, U$4.S
GPB0: IC1.1 (GPB0), R15E6.1
GPB1: IC1.2 (GPB1), R15E3.1
GPB2: IC1.3 (GPB2), R15E2.2
GPB3: IC1.4 (GPB3), R15E1.2
GPB6: IC1.7 (GPB6), R15E20.1, U3.3 (EMITTER)
GPB7: IC1.8 (GPB7), R15E21.1, U4.3 (EMITTER)
IN1: JP4.8, R15E18.2
IN2: JP4.9, R15E19.2
INT-DISPLAY: IC1.24 (GPA3), JP1.5
INT-MCP23017: IC1.20 (INTA), JP1.7
INT-RTC: IC1.25 (GPA4), JP1.2
LED: R15E29.1, SV2.3, U$4.D
unnamed: PTC1.2, Q1.2 (S), R2.1
unnamed: C13.1, U5.1 (C1+)
unnamed: SJ1.2, SV1.4
unnamed: Q1.1 (G), R2.2, U1.6 (PCTLZ)
unnamed: Q2.1 (B), R15E8.2, U2.10 (CT4)
unnamed: R15E2.1, U2.3 (A2)
unnamed: R15E1.1, U2.1 (A1)
unnamed: IC1.21 (GPA0), R15E4.2, SWITCH.2
unnamed: IC1.22 (GPA1), LED-ERROR.2, R15E5.1
unnamed: IC1.23 (GPA2), LED-WIFI.2, R15E9.1
unnamed: R15E3.2, U2.5 (A3)
unnamed: R15E6.2, U2.7 (A4)
unnamed: Q3.1 (B), R15E10.2, U2.12 (CT3)
unnamed: Q4.1 (B), R15E13.2, U2.14 (CT2)
unnamed: C10.1, Q5.1 (B), R15E16.2, U2.16 (CT1)
unnamed: C13.2, U5.3 (C1-)
unnamed: R15E19.1, U4.1 (ANODE)
unnamed: R15E18.1, U3.1 (ANODE)
unnamed: SJ4.1, U$1.2 (ALERT)
unnamed: C12.1, U5.4 (C2+)
unnamed: C12.2, U5.5 (C2-)
unnamed: C14.1, U5.2 (V+)
unnamed: C15.1, U5.6 (V-)
unnamed: R15E24.2, U6.2 (!NRESET)
unnamed: IF-D92.1, R15E14.1
unnamed: C21.1, R15E14.2, R15E22.1, U8.2 (/1B)
unnamed: U6.4 (PWM), U6.5 (SENSE)
unnamed: C20.1, D1.1 (A), R15E23.2, U8.15 (2REXT-CEXT)
OPT1-IN: IC1.6 (GPB5), U8.13 (1Q)
OPT1-RST: IC1.5 (GPB4), U8.3 (/1CLR)
OUT1: JP4.2, Q2.3 (C), R15E7.2
OUT2: JP4.3, Q3.3 (C), R15E11.2
OUT3: JP4.5, Q4.3 (C), R15E12.2
OUT4: JP4.6, Q5.3 (C), R15E15.2
RX-EXP: SJ2.2, SV1.3, U5.9 (ROUT2)
S-GND: C22.-, R15E27.2, SV2.2, SV2.4
SCL: H5.4, IC1.12 (SCL), IC3.4 (SCK), U1.4 (SCL), U6.10 (SCL), U7.2 (SCL/SPC), U$1.10 (SCL), U$2.5 (SCL), U$3.6 (SCL), U$5.6 (SCL)
SDA: H5.3, IC1.13 (SDA), IC3.3 (SDI), U1.5 (SDA), U6.9 (SDA), U7.4 (SDA/SDI/SDO), U$1.9 (SDA), U$2.4 (SDA), U$3.5 (SDA), U$5.5 (SDA)
SIGNALHALL: A3212HALL.2 (OUT), IC1.26 (GPA5), IC4.3 (OUT), R15E17.2
TX-EXP: SJ3.2, SV1.2, U5.10 (DIN2)
V0: R15E26.2, SV2.5
V-LED: C22.+, R15E25.2, SV2.1
VCC-OUT1/4: JP4.4, R15E7.1, R15E8.1, R15E10.1, R15E11.1, R15E12.1, R15E13.1, R15E15.1, R15E16.1
VOUT: C17.1, IC2.2 (OUT), JP6.2

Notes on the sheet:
23017 i2c adress 0x20
flash i2c adress 0x50
use 2k2 pull up or in parasitic mode BSS84 +10K
3.3-24V
Let op voor de 2x2 out Voedingspanning
220 Ohm= input 5V
i2c =5f
i2c=5B
Let op Reset moet aan 3V3 !

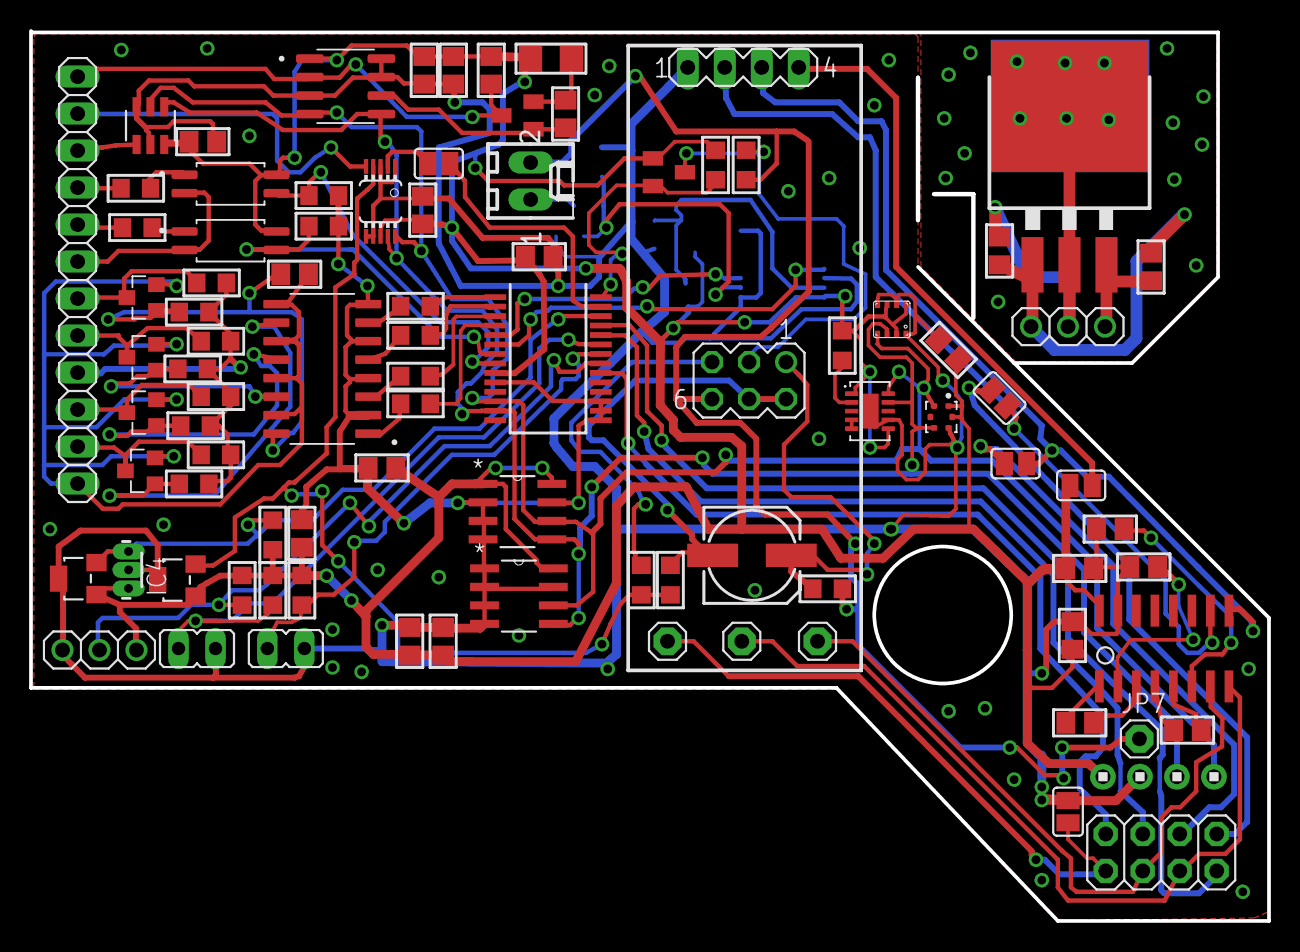
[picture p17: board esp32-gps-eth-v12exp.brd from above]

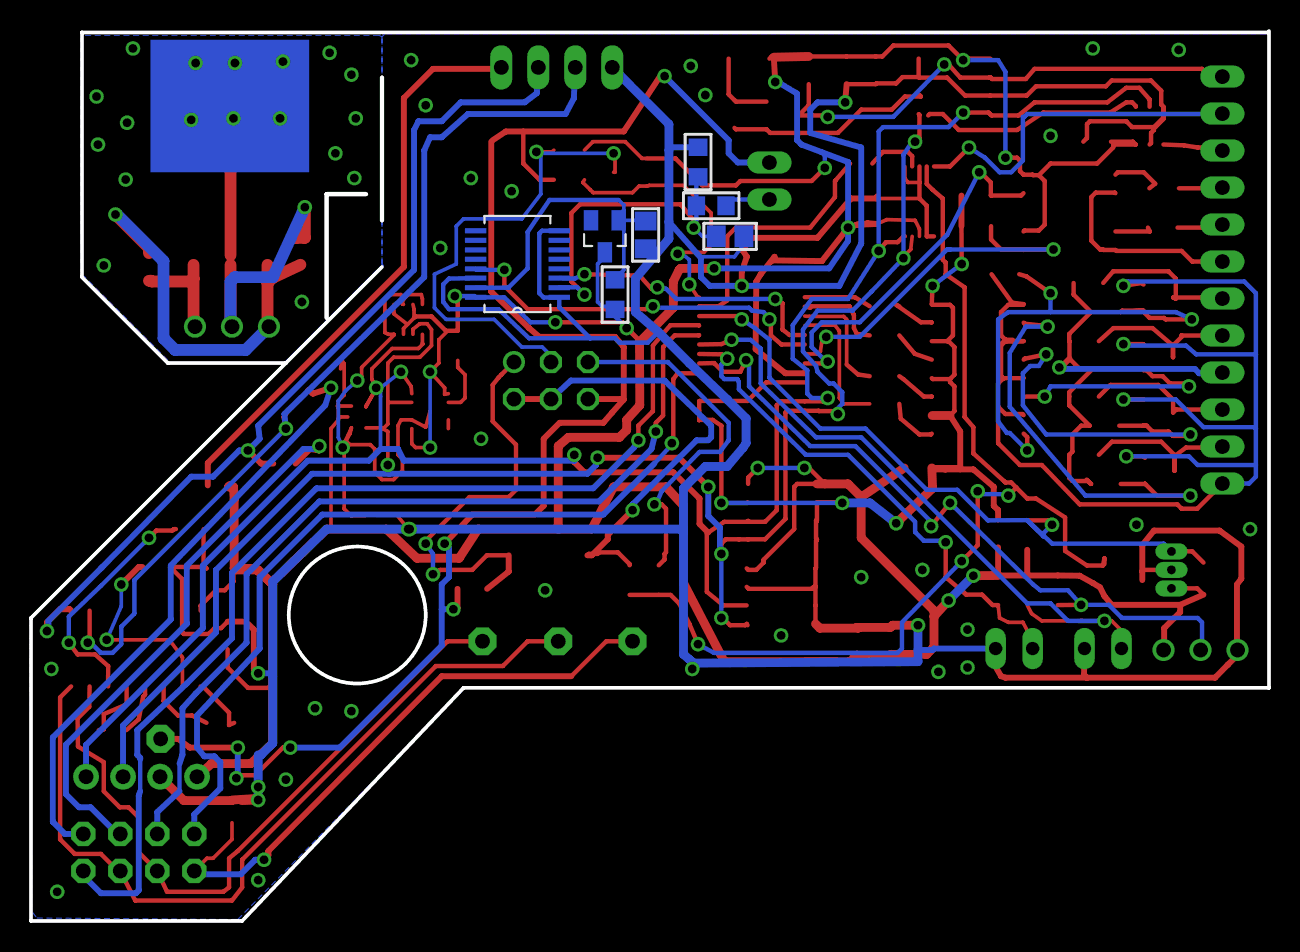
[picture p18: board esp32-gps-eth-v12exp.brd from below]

Board: 2 copper layers, 85.0 x 61.1 mm, 98 parts (7 on the bottom side), 74 nets.

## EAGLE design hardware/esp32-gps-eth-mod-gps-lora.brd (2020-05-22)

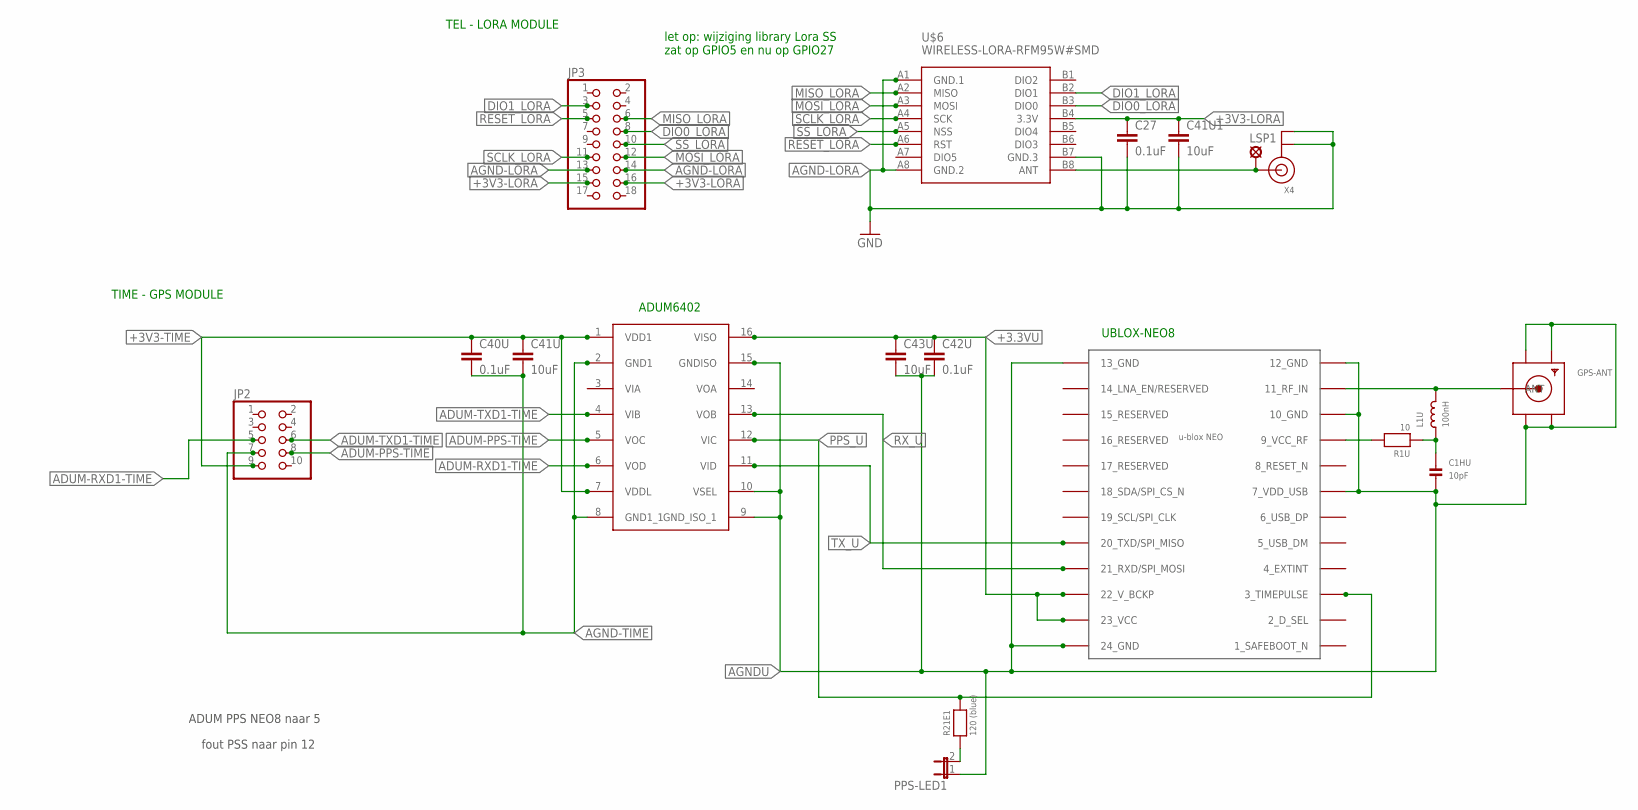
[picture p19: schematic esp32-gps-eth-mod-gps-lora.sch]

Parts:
C1HU: 10pF; _0805
C27, C40U, C42U: 0.1uF; C0805
C41U, C41U1, C43U: 10uF; C0805
GPS-ANT: SMACONNECTOR; SMA90_DIP
JP2: PINHD-2X5/90; 2X05/90
JP3: PINHD-2X9/90; 2X09/90
L1U: 100nH; 0805
LSP1: LSP10
PPS-LED1: JP1E; JP1
R1U: 10; _0805
R21E1: 120 (blue); _0805
U$2: ADUM6402; SOIC16R
U$6: WIRELESS-LORA-RFM95W#SMD
UBLOX-NEO8: NEO-M8
X4: ANTENNA_U.FL; U.FL

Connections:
+3.3VU: C42U.1, C43U.1, U$2.16 (VISO), UBLOX-NEO8.22 (22_V_BCKP), UBLOX-NEO8.23 (23_VCC)
+3V3-LORA: C27.1, C41U1.1, JP3.15, JP3.16, U$6.B4 (3.3V)
+3V3-TIME: C40U.1, C41U.1, JP2.9, U$2.1 (VDD1), U$2.7 (VDDL)
ADUM-PPS-TIME: JP2.8, U$2.5 (VOC)
ADUM-RXD1-TIME: JP2.5, U$2.6 (VOD)
ADUM-TXD1-TIME: JP2.6, U$2.4 (VIB)
AGND-LORA: C27.2, C41U1.2, JP3.13, JP3.14, U$6.A1 (GND.1), U$6.A8 (GND.2), U$6.B7 (GND.3), X4.1 (GND), X4.2 (GND)
AGND-TIME: C40U.2, C41U.2, JP2.7, U$2.2 (GND1), U$2.8 (GND1_1)
AGNDU: C1HU.2, C42U.2, C43U.2, GPS-ANT.GND1, GPS-ANT.GND2, GPS-ANT.GND3, GPS-ANT.GND4, PPS-LED1.1, U$2.9 (GND_ISO_1), U$2.10 (VSEL), U$2.15 (GNDISO), UBLOX-NEO8.7 (7_VDD_USB), UBLOX-NEO8.10 (10_GND), UBLOX-NEO8.12 (12_GND), UBLOX-NEO8.13 (13_GND), UBLOX-NEO8.24 (24_GND)
DIO0_LORA: JP3.8, U$6.B3 (DIO0)
DIO1_LORA: JP3.3, U$6.B2 (DIO1)
MISO_LORA: JP3.6, U$6.A2 (MISO)
MOSI_LORA: JP3.12, U$6.A3 (MOSI)
unnamed: PPS-LED1.2, R21E1.1
unnamed: R1U.2, UBLOX-NEO8.9 (9_VCC_RF)
unnamed: LSP1.MP, U$6.B8 (ANT), X4.3 (SIGNAL)
unnamed: C1HU.1, L1U.1, R1U.1
unnamed: GPS-ANT.ANTENNA (ANT), L1U.2, UBLOX-NEO8.11 (11_RF_IN)
PPS_U: R21E1.2, U$2.12 (VIC), UBLOX-NEO8.3 (3_TIMEPULSE)
RESET_LORA: JP3.5, U$6.A6 (RST)
RX_U: U$2.13 (VOB), UBLOX-NEO8.21 (21_RXD/SPI_MOSI)
SCLK_LORA: JP3.11, U$6.A4 (SCK)
SS_LORA: JP3.10, U$6.A5 (NSS)
TX_U: U$2.11 (VID), UBLOX-NEO8.20 (20_TXD/SPI_MISO)

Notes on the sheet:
ADUM6402
UBLOX-NEO8
ADUM PPS NEO8 naar 5
fout PSS naar pin 12
let op: wijziging library Lora SS zat op GPIO5 en nu op GPIO27
TEL - LORA MODULE
TIME - GPS MODULE

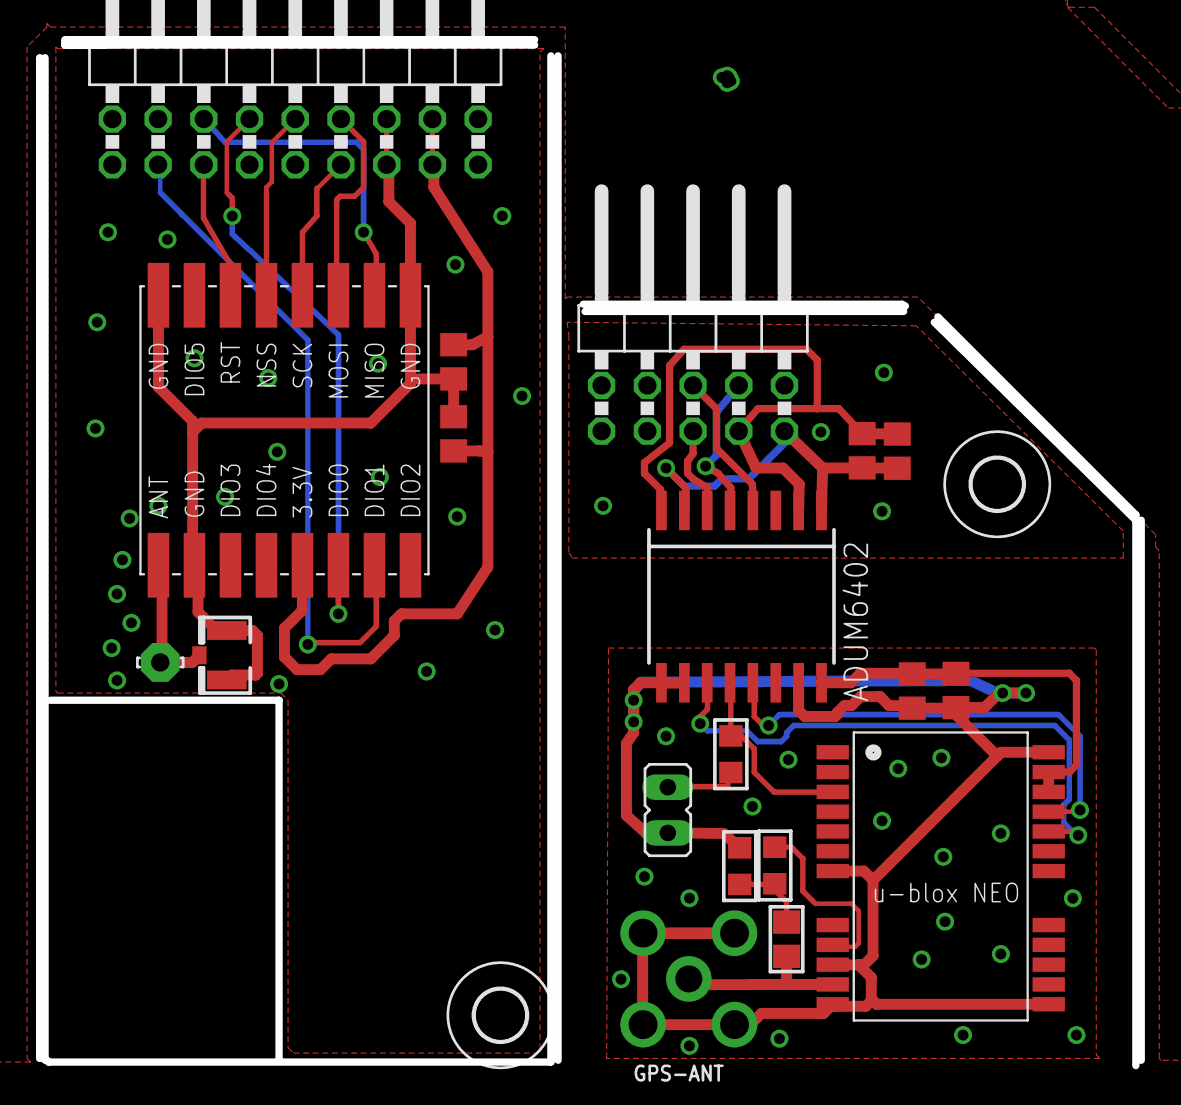
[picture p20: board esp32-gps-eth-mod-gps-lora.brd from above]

Board: 2 copper layers, 61.2 x 57.0 mm, 21 parts (0 on the bottom side), 24 nets.

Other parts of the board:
U$7, U$8: 2,8

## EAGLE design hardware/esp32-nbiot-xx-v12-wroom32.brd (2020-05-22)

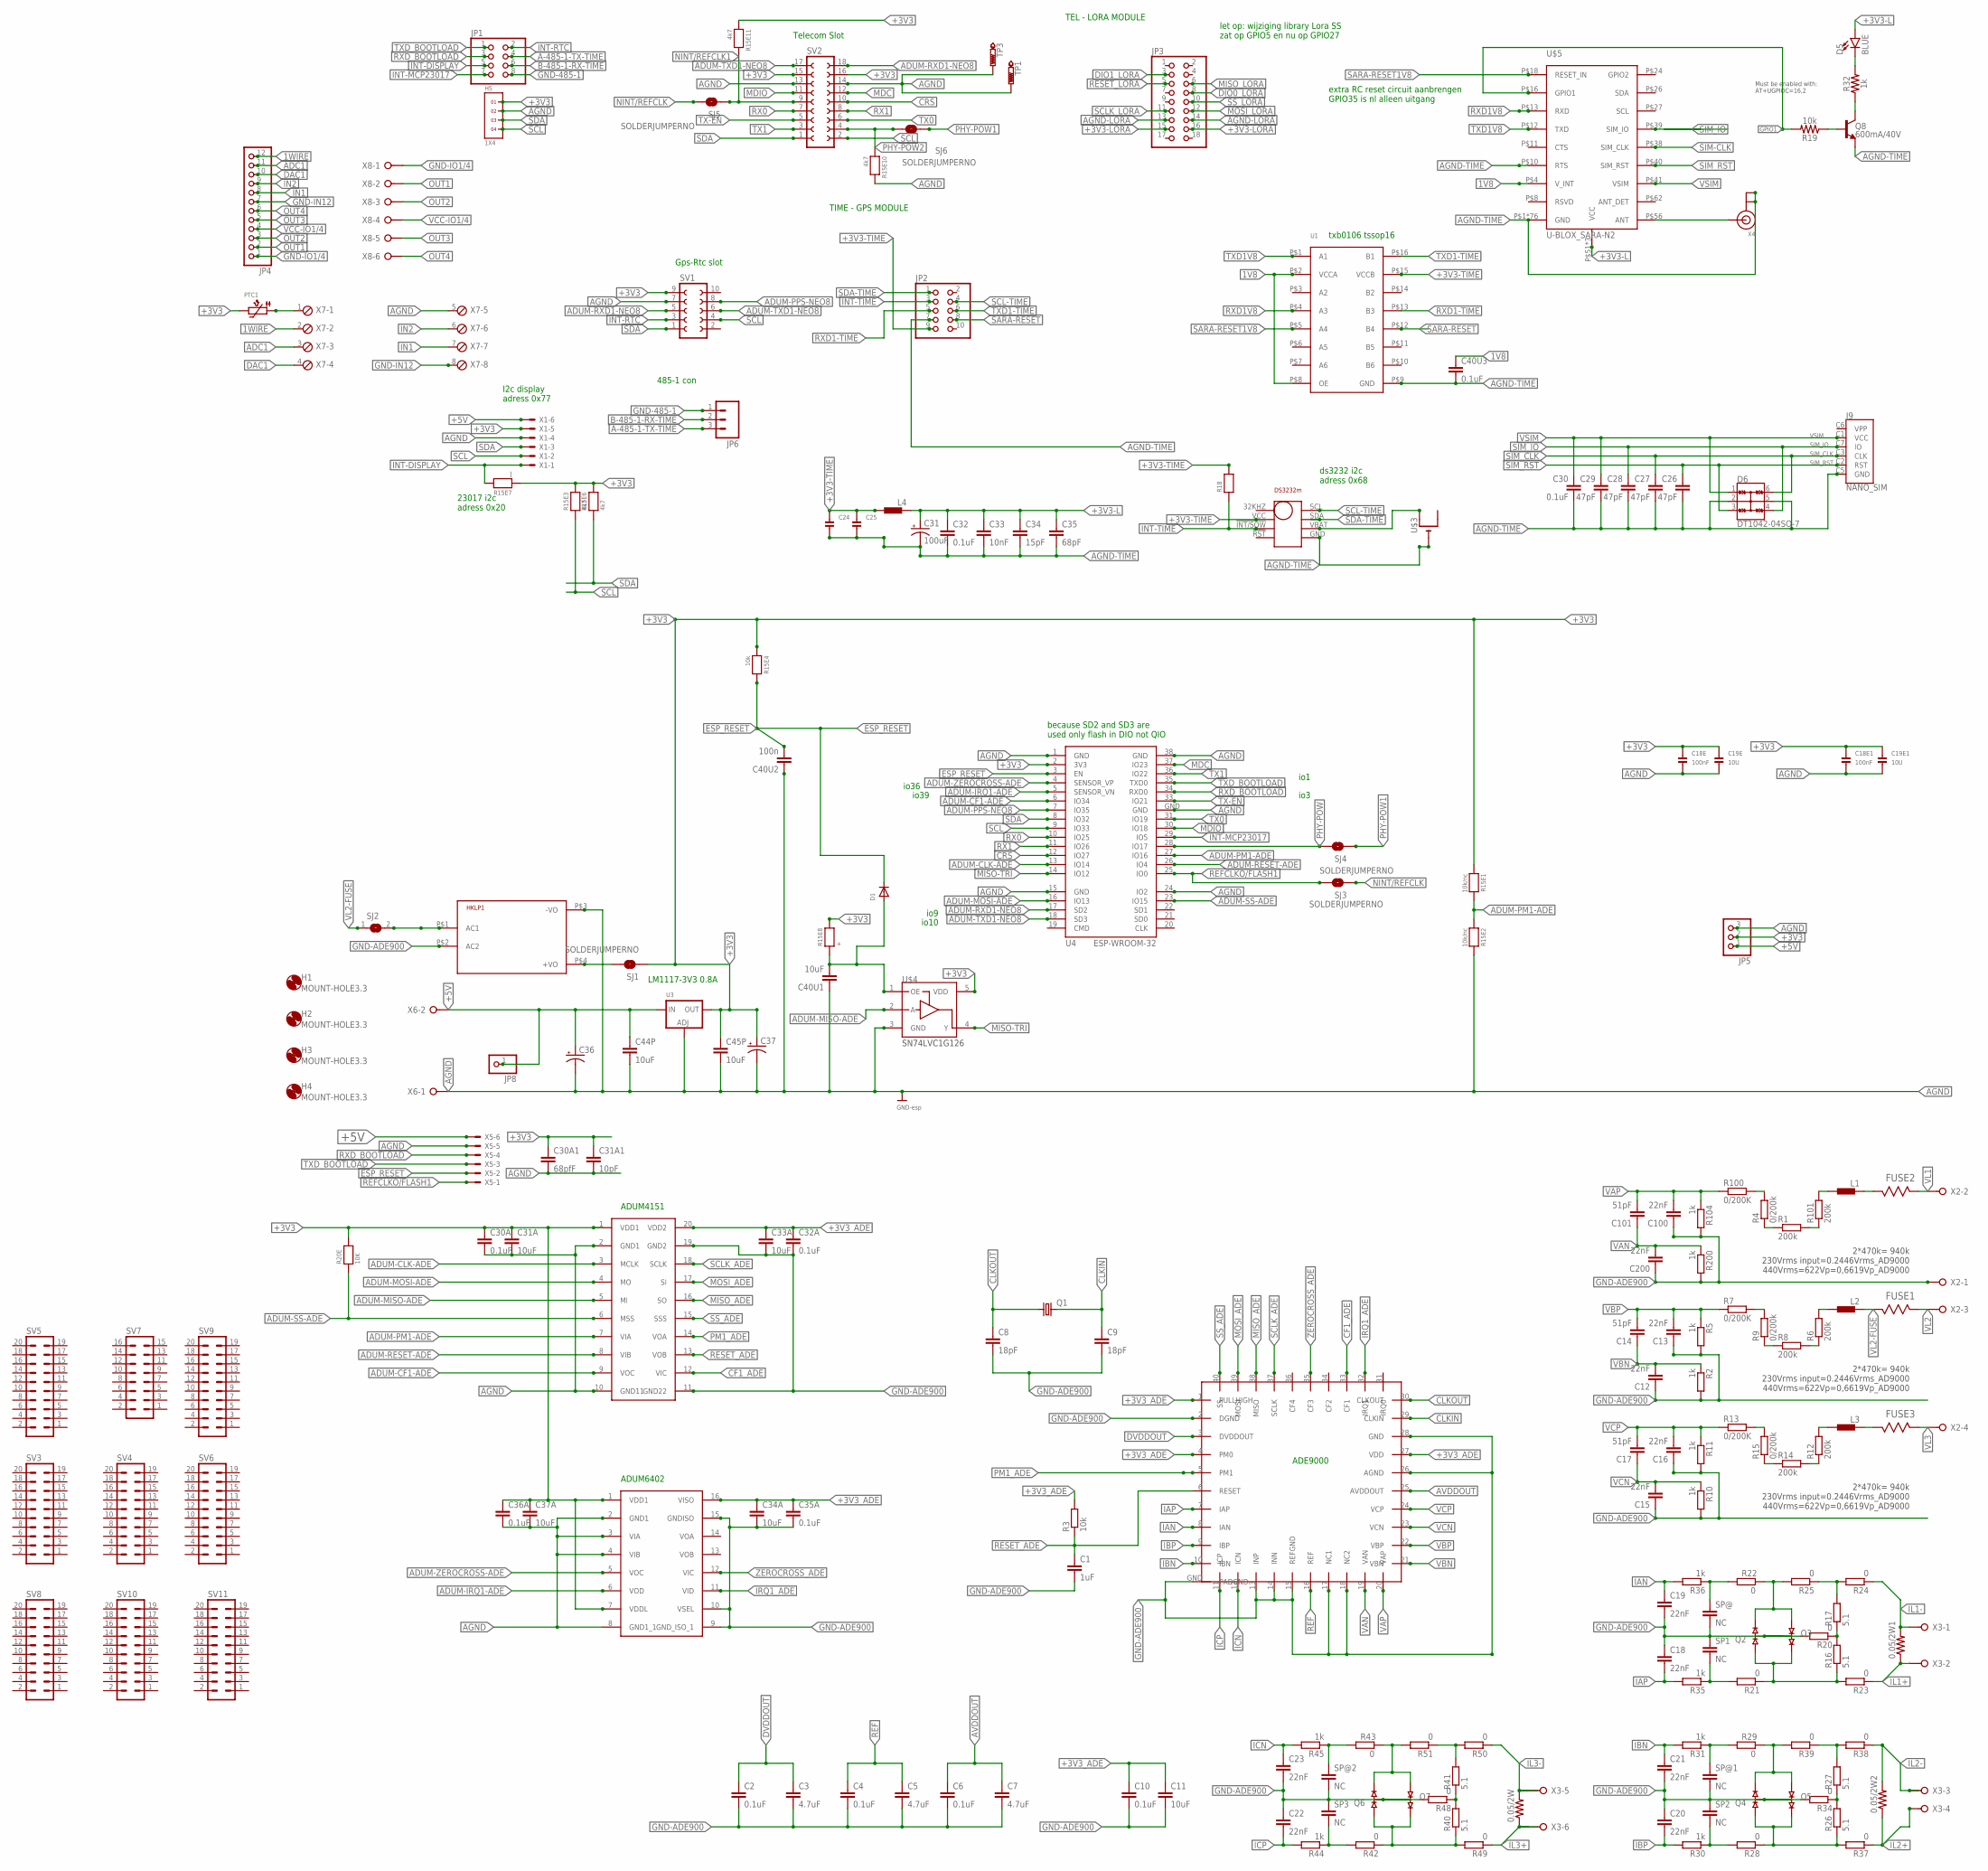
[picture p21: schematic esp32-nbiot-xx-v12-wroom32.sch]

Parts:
0.05/2W, 0.05/2W1, 0.05/2W2: R-US_R4527; R4527
ADE9000: ADE9000; LFCSP40
ADUM4151: ADUM4151; SOIC20R
ADUM6402-2: ADUM6402; SOIC16R
C1: 1uF; C0805
C2, C4, C6, C10, C30A, C32A, C35A, C36A, C40U3: 0.1uF; C0805
C3, C5, C7: 4.7uF; C0805
C8, C9: 18pF; C0805
C11, C31A, C33A, C34A, C37A, C40U1, C44P, C45P: 10uF; C0805
C12, C13, C15, C16, C18, C19, C20, C21, C22, C23, C100, C200: 22nF; C0805
C14, C17, C101: 51pF; C0805
C18E, C18E1: 100nF; _0805
C19E, C19E1: 10U; _0805
C24, C25: CAP_CERAMIC0805; 0805
C26, C27, C28, C29: 47pF; 0603
C30, C32: 0.1uF; 0603
C30A1: 68pfF; C0805
C31: 100uF; 1206-POLAR
C31A1: 10pF; C0805
C33: 10nF; 0603
C34: 15pF; 0603
C35: 68pF; 0603
C36, C37: CPOL-USD/7343-31R; D/7343-31R
C40U2: 100n; C0805
D1: DIODE_SOD-123FL; SOD-123FL
D5: BLUE; LED-0603
D6: DT1042-04SO-7; SOT23-6L
FUSE1, FUSE2, FUSE3: CRCW25124R70JNEG; RESC6332X71N
H1, H2, H3, H4: MOUNT-HOLE3.3; 3,3
H5: 1X4
HKLP1: HKLPM01
J9: NANO_SIM; NANO_SIM_WURTH_693043020611
JP1: PINHD-2X4; 2X04
JP2: PINHD-2X5/90; 2X05/90
JP3: PINHD-2X9/90; 2X09/90
JP4: PINHD-1X12; 1X12
JP5: PINHD-1X3; 1X03
JP6: M03SCREW; SCREWTERMINAL-3.5MM-3
JP8: PINHD-1X1; 1X01
L1, L2, L3, L4: 1500; M0805; DIGIKEY 490-1048-1-ND
PTC1: PTC1206; 1206
Q1: CRYSTALCTS406; CTS406
Q2, Q3, Q4, Q5, Q6, Q7: MMBD4148SE; SOT23-3; DIGIKEY MMBD4148SECT-ND
Q8: 600mA/40V; SOT23-3
R1, R6, R8, R12, R14, R101: 200k; M1206
R2, R5, R10, R11, R104, R200: 1k; M0805
R3: 10k; M0805
R4, R9, R15: 0/200k; M1206
R7, R13, R100: 0/200K; M1206
R15E1, R15E2: 10k/nc; _0805
R15E3, R15E6, R15E10, R15E11: 4k7; _0805
R15E4: 10k; _0805
R15E7: ]; _0805
R15E8: +; _0805
R16, R26, R40: 5.1; R0805; MFR_PART_NO_# CPF0805B5R1E1
R17, R27, R41: 5.1; R0805
R18: RESISTOR0805; 0805
R19: 10k; 0603
R20, R21, R22, R23, R24, R25, R28, R29, R34, R37, R38, R39, R42, R43, R48, R49, R50, R51: 0; R0603
R20E: 10K; _0805
R30, R31, R35, R36, R44, R45: 1k; R0603
R32: 1k; 0603
SJ1, SJ3, SJ4, SJ5, SJ6: SOLDERJUMPERNO; SJ_2S-NO
SJ2: SOLDERJUMPERWAVE; SOLDERJUMPER_WAVE
SP1, SP2, SP3: NC; C0805
SP@, SP@1, SP@2: NC; C0805
SV1: FE05-2W
SV2: FE09-2W
SV3, SV4, SV5, SV6, SV8, SV9, SV10, SV11: MA10-2
SV7: MA08-2
TP1, TP3: PTR1TP08SQ; TP08SQ
U1: TXB0106; TSSOP16
U3: LM1117SOT223-REFLOW; SOT223-R
U4: ESP-WROOM-32
U$1: DS3232M; SOIC8
U$3: CR1220SMT; CR1220-SMD
U$4: SN74LVC1G126DBVT; SOT-23-5L
U$5: U-BLOX_SARA-N2; SARA-N2
X1, X5: 22-23-2061
X2: W237-04P; W237-4P
X3, X8: W237-06P; W237-6P
X4: ANTENNA_U.FL; U.FL
X6: W237-02P; W237-132
X7: MPT8; 8POL254

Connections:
1V8: C40U3.1, U1.P$2 (VCCA), U1.P$8 (OE), U$5.P$4 (V_INT)
1WIRE: JP4.12, X7.2
+3V3: ADUM4151.1 (VDD1), ADUM6402-2.1 (VDD1), ADUM6402-2.7 (VDDL), C18E.1, C18E1.1, C19E.1, C19E1.1, C30A.1, C30A1.1, C31A.1, C31A1.1, C36A.1, C37.+, C37A.1, C45P.1, H5.1, JP5.2, PTC1.2, R15E1.1, R15E3.2, R15E4.1, R15E6.2, R15E7.1, R15E8.2, R15E11.1, R20E.2, SJ1.1, SV1.9, SV2.15, SV2.16, U3.2 (OUT), U4.2 (3V3), U$4.5 (VDD), X1.5
+3V3-L: C31.1 (+), C32.1, C33.1, C34.1, C35.1, D5.A, L4.1, U$5.P$51 (VCC), U$5.P$52 (VCC), U$5.P$53 (VCC)
+3V3-LORA: JP3.15, JP3.16
+3V3-TIME: C24.1, C25.1, JP2.9, L4.2, R18.2, U1.P$15 (VCCB), U$1.VCC
+3V3FUSE: PTC1.1, X7.1
+3V3_ADE: ADE9000.1 (PULLHIGH), ADE9000.4 (PM0), ADE9000.27 (VDD), ADUM4151.20 (VDD2), ADUM6402-2.16 (VISO), C10.1, C11.1, C32A.1, C33A.1, C34A.1, C35A.1, R3.2
+5V: C36.+, C44P.1, JP5.1, JP8.1, U3.3 (IN), X1.6, X5.6, X6.2
A-485-1-TX-TIME: JP1.4, JP6.3
ADC1: JP4.11, X7.3
ADUM-CF1-ADE: ADUM4151.9 (VOC), U4.6 (IO34)
ADUM-CLK-ADE: ADUM4151.3 (MCLK), U4.13 (IO14)
ADUM-IRQ1-ADE: ADUM6402-2.6 (VOD), U4.5 (SENSOR_VN)
ADUM-MISO-ADE: ADUM4151.5 (MI), U$4.2 (A)
ADUM-MOSI-ADE: ADUM4151.4 (MO), U4.16 (IO13)
ADUM-PM1-ADE: ADUM4151.7 (VIA), R15E1.2, R15E2.1, U4.27 (IO16)
ADUM-PPS-NEO8: SV1.8, U4.7 (IO35)
ADUM-RESET-ADE: ADUM4151.8 (VIB), U4.26 (IO4)
ADUM-RXD1-NEO8: SV1.5, SV2.18, U4.17 (SD2)
ADUM-SS-ADE: ADUM4151.6 (MSS), R20E.1, U4.23 (IO15)
ADUM-TXD1-NEO8: SV1.6, SV2.17, U4.18 (SD3)
ADUM-ZEROCROSS-ADE: ADUM6402-2.5 (VOC), U4.4 (SENSOR_VP)
AGND: ADUM4151.2 (GND1), ADUM4151.10 (GND11), ADUM6402-2.2 (GND1), ADUM6402-2.3 (VIA), ADUM6402-2.4 (VIB), ADUM6402-2.8 (GND1_1), C18E.2, C18E1.2, C19E.2, C19E1.2, C30A.2, C30A1.2, C31A.2, C31A1.2, C36.-, C36A.2, C37.-, C37A.2, C40U1.1, C40U2.1, C44P.2, C45P.2, H5.2, HKLP1.P$3 (-VO), JP5.3, R15E2.2, R15E10.2, SV1.7, SV2.13, SV2.14, TP1.TP, TP3.TP, U3.1 (ADJ), U4.1 (GND), U4.15 (GND), U4.24 (IO2), U4.38 (GND), U4.GND, U$4.3 (GND), X1.4, X5.5, X6.1, X7.5
AGND-LORA: JP3.13, JP3.14
AGND-TIME: C24.2, C25.2, C26.2, C27.2, C28.2, C29.2, C30.2, C31.2 (-), C32.2, C33.2, C34.2, C35.2, C40U3.2, D6.2, D6.5, J9.C5 (GND), JP2.7, Q8.2 (E), U1.P$9 (GND), U$1.GND, U$3.-, U$5.P$1 (GND), U$5.P$2 (GND), U$5.P$3 (GND), U$5.P$5 (GND), U$5.P$6 (GND), U$5.P$7 (GND), U$5.P$9 (GND), U$5.P$10 (RTS), U$5.P$14 (GND), U$5.P$15 (GND), U$5.P$17 (GND), U$5.P$19 (GND), U$5.P$20 (GND), U$5.P$21 (GND), U$5.P$22 (GND), U$5.P$23 (GND), U$5.P$25 (GND), U$5.P$28 (GND), U$5.P$29 (GND), U$5.P$30 (GND), U$5.P$31 (GND), U$5.P$32 (GND), U$5.P$33 (GND), U$5.P$34 (GND), U$5.P$35 (GND), U$5.P$36 (GND), U$5.P$37 (GND), U$5.P$42 (GND), U$5.P$43 (GND), U$5.P$44 (GND), U$5.P$45 (GND), U$5.P$46 (GND), U$5.P$47 (GND), U$5.P$48 (GND), U$5.P$49 (GND), U$5.P$50 (GND), U$5.P$54 (GND), U$5.P$55 (GND), U$5.P$57 (GND), U$5.P$58 (GND), U$5.P$59 (GND), U$5.P$60 (GND), U$5.P$61 (GND), U$5.P$63 (GND), U$5.P$64 (GND), U$5.P$65 (GND), U$5.P$66 (GND), U$5.P$67 (GND), U$5.P$68 (GND), U$5.P$69 (GND), U$5.P$70 (GND), U$5.P$71 (GND), U$5.P$72 (GND), U$5.P$73 (GND), U$5.P$74 (GND), U$5.P$75 (GND), U$5.P$76 (GND), U$5.P$77 (GND), U$5.P$78 (GND), U$5.P$79 (GND), U$5.P$80 (GND), U$5.P$81 (GND), U$5.P$82 (GND), U$5.P$83 (GND), U$5.P$84 (GND), U$5.P$85 (GND), U$5.P$86 (GND), U$5.P$87 (GND), U$5.P$88 (GND), U$5.P$89 (GND), U$5.P$90 (GND), U$5.P$91 (GND), U$5.P$92 (GND), U$5.P$93 (GND), U$5.P$94 (GND), U$5.P$95 (GND), U$5.P$96 (GND), X4.1 (GND), X4.2 (GND)
AVDDOUT: ADE9000.25 (AVDDOUT), C6.1, C7.1
B-485-1-RX-TIME: JP1.6, JP6.2
CF1_ADE: ADE9000.33 (CF1), ADUM4151.12 (VIC)
CLKIN: ADE9000.29 (CLKIN), C9.1, Q1.3 (2)
CLKOUT: ADE9000.30 (CLKOUT), C8.1, Q1.1
CRS: SV2.10, U4.12 (IO27)
DAC1: JP4.10, X7.4
DIO0_LORA: JP3.8
DIO1_LORA: JP3.3
DVDDOUT: ADE9000.3 (DVDDOUT), C2.1, C3.1
ESP_RESET: C40U2.2, D1.C, R15E4.2, U4.3 (EN), X5.2
GND-485-1: JP1.8, JP6.1
GND-ADE900: ADE9000.2 (DGND), ADE9000.13 (INP), ADE9000.14 (INN), ADE9000.15 (REFGND), ADE9000.17 (NC1), ADE9000.18 (NC2), ADE9000.26 (AGND), ADE9000.28 (GND), ADE9000.GND, ADUM4151.11 (GND22), ADUM4151.19 (GND2), ADUM6402-2.9 (GND_ISO_1), ADUM6402-2.10 (VSEL), ADUM6402-2.15 (GNDISO), C1.2, C2.2, C3.2, C4.2, C5.2, C6.2, C7.2, C8.2, C9.2, C10.2, C11.2, C12.1, C13.1, C15.1, C16.1, C18.1, C19.2, C20.1, C21.2, C22.1, C23.2, C32A.2, C33A.2, C34A.2, C35A.2, C100.1, C200.1, HKLP1.P$2 (AC2), Q2.3, Q3.3, Q4.3, Q5.3, Q6.3, Q7.3, R2.2, R5.2, R10.2, R11.2, R20.2, R34.2, R48.2, R104.2, R200.2, SP1.1, SP2.1, SP3.1, SP@.2, SP@1.2, SP@2.2, X2.1
GND-IN12: JP4.7, X7.8
GND-IO1/4: JP4.1, X8.1
GPIO1: R19.2, U$5.P$16 (GPIO1)
IAN: ADE9000.8 (IAN), C19.1, R36.2
IAP: ADE9000.7 (IAP), C18.2, R35.2
IBN: ADE9000.10 (IBN), C21.1, R31.2
IBP: ADE9000.9 (IBP), C20.2, R30.2
ICN: ADE9000.12 (ICN), C23.1, R45.2
ICP: ADE9000.11 (ICP), C22.2, R44.2
IL1+: 0.05/2W1.1, R23.1, X3.2
IL1-: 0.05/2W1.2, R24.1, X3.1
IL2+: 0.05/2W2.1, R37.1, X3.4
IL2-: 0.05/2W2.2, R38.1, X3.3
IL3+: 0.05/2W.1, R49.1, X3.6
IL3-: 0.05/2W.2, R50.1, X3.5
IN1: JP4.8, X7.7
IN2: JP4.9, X7.6
INT-DISPLAY: JP1.5, R15E7.2, X1.1
INT-MCP23017: JP1.7, U4.29 (IO5)
INT-RTC: JP1.2, SV1.3
INT-TIME: JP2.3, R18.1, U$1.!INT/!!SQW
IRQ1_ADE: ADE9000.32 (IRQ1), ADUM6402-2.11 (VID)
MDC: SV2.12, U4.37 (IO23)
MDIO: SV2.11, U4.30 (IO18)
MISO-TRI: U4.14 (IO12), U$4.4 (Y)
MISO_ADE: ADE9000.38 (MISO), ADUM4151.16 (SO)
MISO_LORA: JP3.6
MOSI_ADE: ADE9000.39 (MOSI), ADUM4151.17 (SI)
MOSI_LORA: JP3.12
unnamed: L2.2, R6.2
unnamed: Q2.1, Q3.2, R16.1, R21.1, R23.2
unnamed: R7.2, R9.2
unnamed: R8.1, R9.1
unnamed: C40U1.2, D1.A, R15E8.1, U$4.1 (OE)
unnamed: U$1.VBAT, U$3.+$1 (+)
unnamed: R6.1, R8.2
unnamed: Q2.2, Q3.1, R22.2, R25.2
unnamed: L3.2, R12.2
unnamed: FUSE3.1, L3.1
unnamed: R13.2, R15.2
unnamed: R14.1, R15.1
unnamed: R12.1, R14.2
unnamed: R22.1, R36.1, SP@.1
unnamed: Q8.1 (B), R19.1
unnamed: R16.2, R17.1, R20.1
unnamed: HKLP1.P$1 (AC1), SJ2.2
unnamed: R17.2, R24.2, R25.1
unnamed: Q4.1, Q5.2, R26.1, R28.1, R37.2
unnamed: D5.C, R32.2
unnamed: Q4.2, Q5.1, R29.2, R39.2
unnamed: R29.1, R31.1, SP@1.1
unnamed: Q8.3 (C), R32.1
unnamed: U$5.P$56 (ANT), X4.3 (SIGNAL)
unnamed: R28.2, R30.1, SP2.2
unnamed: R4.2, R100.2
unnamed: R26.2, R27.1, R34.1
unnamed: L1.2, R101.2
unnamed: R27.2, R38.2, R39.1
unnamed: R1.1, R4.1
unnamed: R1.2, R101.1
unnamed: R21.2, R35.1, SP1.2
unnamed: Q6.1, Q7.2, R40.1, R42.1, R49.2
unnamed: Q6.2, Q7.1, R43.2, R51.2
unnamed: R43.1, R45.1, SP@2.1
unnamed: R42.2, R44.1, SP3.2
unnamed: R40.2, R41.1, R48.1
unnamed: R41.2, R50.2, R51.1
unnamed: HKLP1.P$4 (+VO), SJ1.2
NINT/REFCLK: SJ3.1, SJ5.2
NINT/REFCLK1: R15E11.2, SJ5.1, SV2.9
OUT1: JP4.2, X8.2
OUT2: JP4.3, X8.3
OUT3: JP4.5, X8.5
OUT4: JP4.6, X8.6
PHY-POW: SJ4.2, U4.28 (IO17)
PHY-POW1: SJ4.1, SJ6.1
PHY-POW2: R15E10.1, SJ6.2, SV2.4
PM1_ADE: ADE9000.5 (PM1), ADUM4151.14 (VOA)
REF: ADE9000.16 (REF), C4.1, C5.1
REFCLKO/FLASH1: SJ3.2, U4.25 (IO0), X5.1
RESET_ADE: ADE9000.6 (RESET), ADUM4151.13 (VOB), C1.1, R3.1
RESET_LORA: JP3.5
RX0: SV2.7, U4.10 (IO25)
RX1: SV2.8, U4.11 (IO26)
RXD1-TIME: JP2.5, U1.P$13 (B3)
RXD1V8: U1.P$4 (A3), U$5.P$13 (RXD)
RXD_BOOTLOAD: JP1.3, U4.34 (RXD0), X5.4
SARA-RESET: JP2.8, U1.P$12 (B4)
SARA-RESET1V8: U1.P$5 (A4), U$5.P$18 (RESET_IN)
SCL: H5.4, R15E3.1, SV1.4, SV2.2, U4.9 (IO33), X1.2
SCL-TIME: JP2.4, U$1.SCL
SCLK_ADE: ADE9000.37 (SCLK), ADUM4151.18 (SCLK)
SCLK_LORA: JP3.11
SDA: H5.3, R15E6.1, SV1.1, SV2.1, U4.8 (IO32), X1.3
SDA-TIME: JP2.1, U$1.SDA
SIM-CLK: U$5.P$38 (SIM_CLK)
SIM_CLK: C27.1, D6.6, J9.C3 (CLK)
SIM_IO: C28.1, D6.4, J9.C7 (IO), U$5.P$39 (SIM_IO)
SIM_RST: C26.1, D6.3, J9.C2 (RST), U$5.P$40 (SIM_RST)
SS_ADE: ADE9000.40 (SS), ADUM4151.15 (SSS)
SS_LORA: JP3.10
TX0: SV2.6, U4.31 (IO19)
TX1: SV2.3, U4.36 (IO22)
TX-EN: SV2.5, U4.33 (IO21)
TXD1-TIME: JP2.6, U1.P$16 (B1)
TXD1V8: U1.P$1 (A1), U$5.P$12 (TXD)
TXD_BOOTLOAD: JP1.1, U4.35 (TXD0), X5.3
VAN: ADE9000.19 (VAN), C101.1, C200.2, R200.1
VAP: ADE9000.20 (VAP), C100.2, C101.2, R100.1, R104.1
VBN: ADE9000.21 (VBN), C12.2, C14.1, R2.1
VBP: ADE9000.22 (VBP), C13.2, C14.2, R5.1, R7.1
VCC-IO1/4: JP4.4, X8.4
VCN: ADE9000.23 (VCN), C15.2, C17.1, R10.1
VCP: ADE9000.24 (VCP), C16.2, C17.2, R11.1, R13.1
VL1: FUSE2.2, X2.2
VL1-FUSE: FUSE2.1, L1.1
VL2: FUSE1.2, X2.3
VL2-FUSE: FUSE1.1, L2.1, SJ2.1
VL3: FUSE3.2, X2.4
VSIM: C29.1, C30.1, D6.1, J9.C1 (VCC), U$5.P$41 (VSIM)
ZEROCROSS_ADE: ADE9000.35 (CF3), ADUM6402-2.12 (VIC)

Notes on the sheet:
ADUM4151
2*470k= 940k 230Vrms input=0.2446Vrms_AD9000 440Vrms=622Vp=0,6619Vp_AD9000
ADE9000
ADUM6402
LM1117-3V3 0.8A
23017 i2c adress 0x20
I2c display adress 0x77
Telecom Slot
Gps-Rtc slot
let op: wijziging library Lora SS zat op GPIO5 en nu op GPIO27
TEL - LORA MODULE
TIME - GPS MODULE
485-1 con
io36
io39
io1
io3
because SD2 and SD3 are used only flash in DIO not QIO
io9
io10
ds3232 i2c adress 0x68
Must be enabled with: AT+UGPIOC=16,2
txb0106 tssop16
extra RC reset circuit aanbrengen GPIO35 is nl alleen uitgang

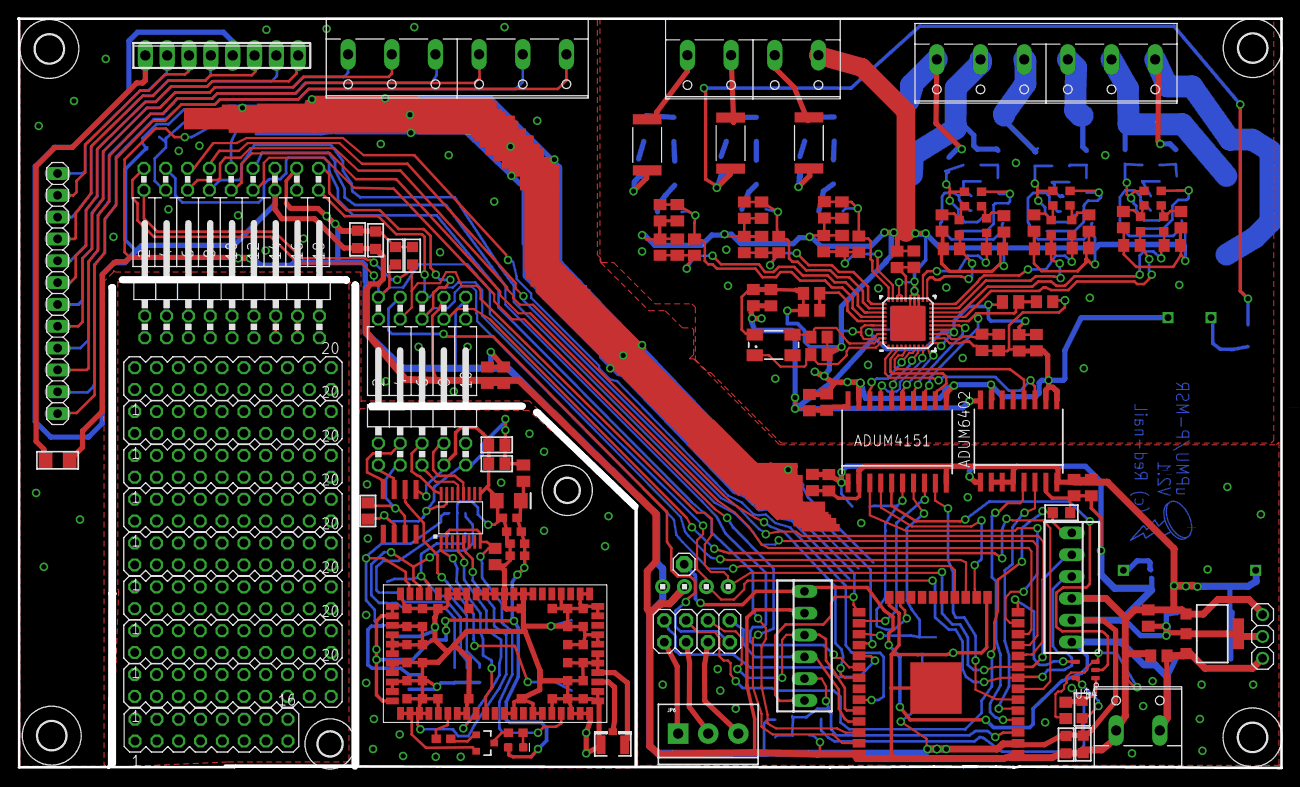
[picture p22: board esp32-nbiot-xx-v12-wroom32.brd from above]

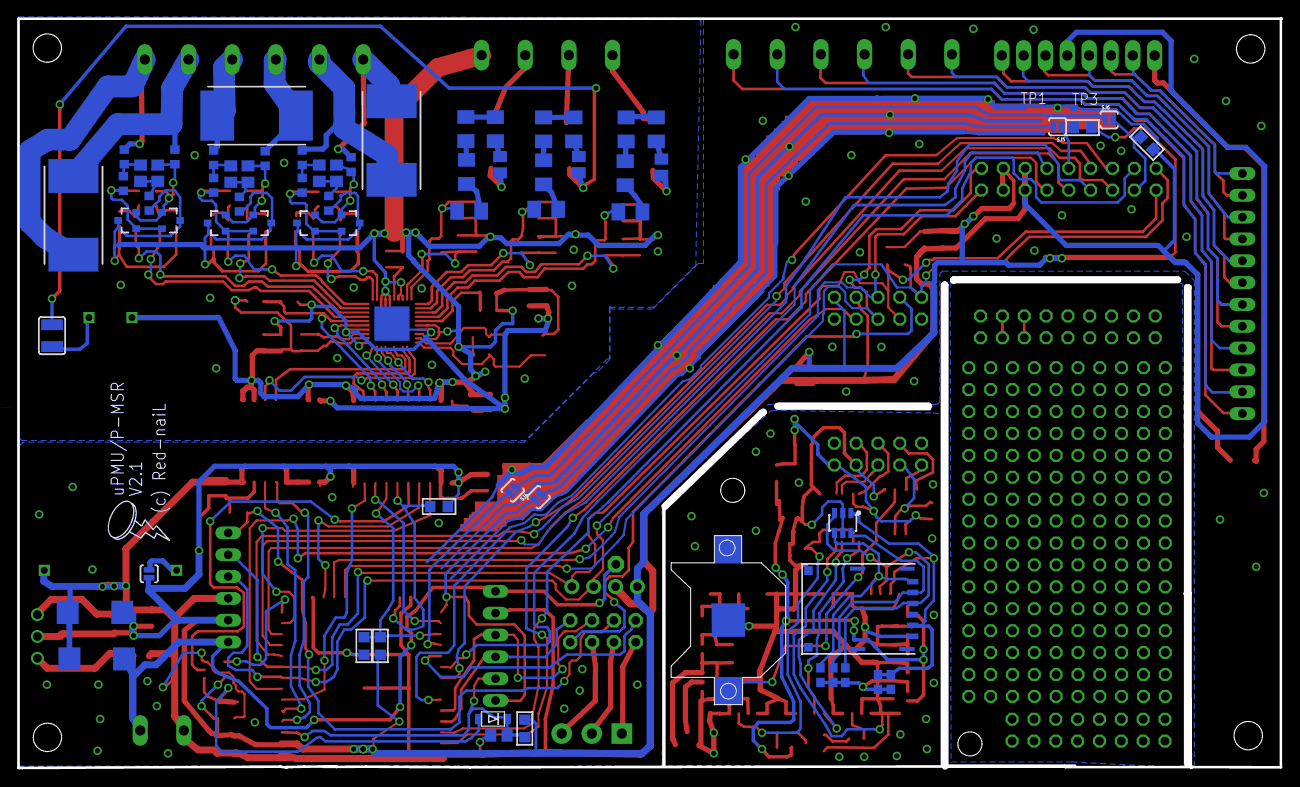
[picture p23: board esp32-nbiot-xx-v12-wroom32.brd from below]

Board: 2 copper layers, 146.9 x 87.2 mm, 202 parts (68 on the bottom side), 152 nets.

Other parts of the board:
U$7, U$8: 2,8

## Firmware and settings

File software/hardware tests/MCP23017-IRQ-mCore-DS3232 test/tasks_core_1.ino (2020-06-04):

//***********************  IRQ MCP23017 at Gpio 5**************************************************
void IRAM_ATTR InterruptMCP() 
{portENTER_CRITICAL_ISR(&mux);
 interruptMCPoccur=1;
 portEXIT_CRITICAL_ISR(&mux);
}
//**************************************************************************************************

//****************** Core 1 main task (I2C Display, Communication) ********************************
void Core1_main( void * parameter )
{//***** setup part  ***
#ifdef RTC
  myRTC.begin();
#endif
  MCP23017start();
#ifdef DEBUG  
  Serial.println("core1-main task:alive");
  LedTest();
  Presskey();
  #ifdef RTC
    RTCtest();
  #endif
#endif  
 interruptMCPoccur=0;
 mcp.clearInterrupts();
 attachInterrupt(digitalPinToInterrupt(INT_MCP23017pin),InterruptMCP, FALLING);  // Active low so falling INT 
 #ifdef RTC
   DS3232Alarmread_reset(); 
   #ifdef DEBUG
     Serial.println("interrupt routine activated");
   #endif
 #endif
 //***** loop part   ***
 for(;;)
 {

  
  vTaskDelay(1);
 }
 vTaskDelete( NULL );
}
//*************************************************************************************************
//****************** Core 1 second task IRQ MCP23017 handling (RTC, Display, I/O etc) *************
//****************** This task looks if the interrupt from the MCP23017 is triggered  *************
//****************** in the main task (setup part) in the subroutine mcp23017start    *************
//****************** the MCP triggers and flags are defined                           *************
//****************** This task finds out which input line of the MCP23017 caused this *************
//****************** See in decleration part of theis soft ware and the EAGLE         *************
//****************** schematics for details                                           *************
void Core1_irqcheckMCP( void * parameter )
{//***** setup part  ***
 uint8_t PortA_INT_cap,PortB_INT_cap,PortA_INT_cap_old,PortB_INT_cap_old;    // for the flag capture register of the MCP23017 ..(latched registers and cleared when read
 uint8_t statRTCreg;
 bool INTCAPChangedDuringExicution;
 #ifdef DEBUG
   Serial.println("core1-irq MCP handling task:alive");
 #endif
 //***** loop part   ***
 for(;;)
 {if (interruptMCPoccur==1)
   {// ****************** make sub for checking INT CAP changes during procedure !!!!!@
    // read flag capture latch registers
    mcp.readRegister(MCP23017Register::INTCAP_A,PortA_INT_cap,PortB_INT_cap); 
    PortA_INT_cap_old=PortA_INT_cap;
    PortB_INT_cap_old=PortB_INT_cap;
    INTCAPChangedDuringExicution= true;
    while (INTCAPChangedDuringExicution==true)
     {// now find out which bit flag in portA and the value (was it falling than bit =0)
      IdentWhichInterruptMCP23017(PortA_INT_cap,PortB_INT_cap);
      // flags for interrupt identification are set
      // check for changes in INTCAP register ..may be an extra interrupt during execution of 'IdentWhichInterruptMCP23017' routine
      mcp.readRegister(MCP23017Register::INTCAP_A,PortA_INT_cap,PortB_INT_cap); 
      if ((PortA_INT_cap != PortA_INT_cap_old)||(PortB_INT_cap != PortB_INT_cap_old))
        {INTCAPChangedDuringExicution==true; 
         PortA_INT_cap_old=PortA_INT_cap;
         PortB_INT_cap_old=PortB_INT_cap;  
        }
      else
        {INTCAPChangedDuringExicution= false;
        }
     }
    //after all the interrupt are checked and flagged...clear the MCP23017
    mcp.clearInterrupts();
    interruptMCPoccur=0;  
   }
   vTaskDelay(1);
 }
 vTaskDelete( NULL ); 
}
//*************************************************************************************************










/*

//*******************main loop************************
void loop() {
  // put your main code here, to run repeatedly:
  uint16_t PortAB;
  if (interruptoccur==1)
    { interruptdetect=1;
      Serial.println("interrupt found"); 
     myRTC.alarm(ALARM_1);
     myRTC.alarm(ALARM_2);
     mcp.clearInterrupts();
     interruptoccur=0;
     interruptdetect=0;
    }
  myRTC.read(tm);
  PortAB=mcp.read();
  Serial.print("Actual DS3232 time: ");
  Serial.print(tm.Day,DEC);Serial.print('/');Serial.print(tm.Month,DEC);Serial.print('/');Serial.print(tm.Year,DEC);Serial.print(' ');
  Serial.print(tm.Hour,DEC);Serial.print(":");Serial.print(tm.Minute,DEC);Serial.print(":");Serial.print(tm.Second,DEC);Serial.print(' ');
  Serial.println(PortAB,BIN);
  delay(100);  //so every 1/10th of a second
}

//****************** IRQ MCP23017 *************************
void INT_Handling_MCP23017()
{// select which interrupt occured
 uint8_t PortA_INT_flag,PortB_INT_flag;

 uint8_t PortA_INT_cap,PortB_INT_cap;
 //portENTER_CRITICAL_ISR(&mux);
 //
 if (interruptdetect==0)
   {interruptMCPoccur=1;
    interruptdetect=1;}
 //portEXIT_CRITICAL_ISR(&mux);
 
 mcp.interruptedBy(PortA_INT_flag,PortB_INT_flag);
 Serial.println("Interrupt at mcp2307");
 if (PortA_INT_flag != 0)
   {PortA_INT_cap=mcp.readRegister(MCP23017Register::INTCAP_A);  
    // now find out which bit flag in portA and the value (was it falling than bit =0)
    //****check for DS3232 ALARM ****      ******needs rework for Alarm1 and Alarm2 
    if ((PortA_INT_flag & 0b00010000)&&(!(PortA_INT_cap | 0b11101111))) 
      {//interrupt caused by DS3232 Alarm
       //find out alarm1 or alarm2
       if (myRTC.alarm(1))
         {//alarm1 interrupt routine
          myRTC.read(tm);
          Serial.print("Alarm1 at: ");
          Serial.print(tm.Day,DEC);Serial.print('/');Serial.print(tm.Month,DEC);Serial.print('/');Serial.print(tm.Year,DEC);Serial.print(' ');
          Serial.print(tm.Hour,DEC);Serial.print(":");Serial.print(tm.Minute,DEC);Serial.print(":");Serial.println(tm.Second,DEC);
         
         }
       if (myRTC.alarm(2))
         {//alarm2 interrupt routine
          myRTC.read(tm);
          Serial.print("Alarm2 at: ");
          Serial.print(tm.Day,DEC);Serial.print('/');Serial.print(tm.Month,DEC);Serial.print('/');Serial.print(tm.Year,DEC);Serial.print(' ');
          Serial.print(tm.Hour,DEC);Serial.print(":");Serial.print(tm.Minute,DEC);Serial.print(":");Serial.println(tm.Second,DEC);
         
         }
      }
    // here the routines for the other interrupts
   }
 if (PortB_INT_flag != 0)  
   {PortB_INT_cap=mcp.readRegister(MCP23017Register::INTCAP_B);
    
   }
  
}

*/

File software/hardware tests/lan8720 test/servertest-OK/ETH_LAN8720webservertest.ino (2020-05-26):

/*
   Copyright (c) 2015, Majenko Technologies
   All rights reserved.

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
 * * Neither the name of Majenko Technologies nor the names of its
     contributors may be used to endorse or promote products derived from
     this software without specific prior written permission.

   THIS SOFTWARE IS PROVIDED BY THE COPYRIGHT HOLDERS AND CONTRIBUTORS "AS IS" AND
   ANY EXPRESS OR IMPLIED WARRANTIES, INCLUDING, BUT NOT LIMITED TO, THE IMPLIED
   WARRANTIES OF MERCHANTABILITY AND FITNESS FOR A PARTICULAR PURPOSE ARE
   DISCLAIMED. IN NO EVENT SHALL THE COPYRIGHT HOLDER OR CONTRIBUTORS BE LIABLE FOR
   ANY DIRECT, INDIRECT, INCIDENTAL, SPECIAL, EXEMPLARY, OR CONSEQUENTIAL DAMAGES
   (INCLUDING, BUT NOT LIMITED TO, PROCUREMENT OF SUBSTITUTE GOODS OR SERVICES;
   LOSS OF USE, DATA, OR PROFITS; OR BUSINESS INTERRUPTION) HOWEVER CAUSED AND ON
   ANY THEORY OF LIABILITY, WHETHER IN CONTRACT, STRICT LIABILITY, OR TORT
   (INCLUDING NEGLIGENCE OR OTHERWISE) ARISING IN ANY WAY OUT OF THE USE OF THIS
   SOFTWARE, EVEN IF ADVISED OF THE POSSIBILITY OF SUCH DAMAGE.
*/

//#include <WiFi.h>
//#include <WiFiClient.h>
#include <WebServer.h>
#include <ESPmDNS.h>
#include <ETH.h>

/* 
   * ETH_CLOCK_GPIO0_IN   - default: external clock from crystal oscillator
   * ETH_CLOCK_GPIO0_OUT  - 50MHz clock from internal APLL output on GPIO0 - possibly an inverter is needed for LAN8720
   * ETH_CLOCK_GPIO16_OUT - 50MHz clock from internal APLL output on GPIO16 - possibly an inverter is needed for LAN8720
   * ETH_CLOCK_GPIO17_OUT - 50MHz clock from internal APLL inverted output on GPIO17 - tested with LAN8720
*/
#define ETH_CLK_MODE    ETH_CLOCK_GPIO0_IN
// Pin# of the enable signal for the external crystal oscillator (-1 to disable for internal APLL source)
#define ETH_POWER_PIN   17
// Type of the Ethernet PHY (LAN8720 or TLK110)
#define ETH_TYPE        ETH_PHY_LAN8720
// I²C-address of Ethernet PHY (0 or 1 for LAN8720, 31 for TLK110)                                                                                                                                                                                                                                                                                                                                                                                          
#define ETH_ADDR        1
// Pin# of the I²C clock signal for the Ethernet PHY
#define ETH_MDC_PIN     23
// Pin# of the I²C IO signal for the Ethernet PHY
#define ETH_MDIO_PIN    18


static bool eth_connected = false;
//const char *ssid = "YourSSIDHere";
//const char *password = "YourPSKHere";

WebServer server(80);


void handleRoot() {
 
  char temp[400];
  int sec = millis() / 1000;
  int min = sec / 60;
  int hr = min / 60;

  snprintf(temp, 400,

           "<html>\
  <head>\
    <meta http-equiv='refresh' content='5'/>\
    <title>ESP32 Demo</title>\
    <style>\
      body { background-color: #cccccc; font-family: Arial, Helvetica, Sans-Serif; Color: #000088; }\
    </style>\
  </head>\
  <body>\
    <h1>Hello from ESP32!</h1>\
    <p>Uptime: %02d:%02d:%02d</p>\
    <img src=\"/test.svg\" />\
  </body>\
</html>",

           hr, min % 60, sec % 60
          );
  server.send(200, "text/html", temp);

}

void handleNotFound() {

  String message = "File Not Found\n\n";
  message += "URI: ";
  message += server.uri();
  message += "\nMethod: ";
  message += (server.method() == HTTP_GET) ? "GET" : "POST";
  message += "\nArguments: ";
  message += server.args();
  message += "\n";

  for (uint8_t i = 0; i < server.args(); i++) {
    message += " " + server.argName(i) + ": " + server.arg(i) + "\n";
  }

  server.send(404, "text/plain", message);
  
}

void WiFiEvent(WiFiEvent_t event) {
  switch (event) {
    case SYSTEM_EVENT_ETH_START:
      Serial.println("ETH Started");
      //set eth hostname here
      ETH.setHostname("esp32-ethernet");
      break;
    case SYSTEM_EVENT_ETH_CONNECTED:
      Serial.println("ETH Connected");
      break;
    case SYSTEM_EVENT_ETH_GOT_IP:
      Serial.print("ETH MAC: ");
      Serial.print(ETH.macAddress());
      Serial.print(", IPv4: ");
      Serial.print(ETH.localIP());
      if (ETH.fullDuplex()) {
        Serial.print(", FULL_DUPLEX");
      }
      Serial.print(", ");
      Serial.print(ETH.linkSpeed());
      Serial.println("Mbps");
      eth_connected = true;
      break;
    case SYSTEM_EVENT_ETH_DISCONNECTED:
      Serial.println("ETH Disconnected");
      eth_connected = false;
      break;
    case SYSTEM_EVENT_ETH_STOP:
      Serial.println("ETH Stopped");
      eth_connected = false;
      break;
    default:
      break;
  }
}

void setup(void) {
  
  Serial.begin(115200);

  WiFi.onEvent(WiFiEvent);
  ETH.begin(ETH_ADDR, ETH_POWER_PIN, ETH_MDC_PIN, ETH_MDIO_PIN, ETH_TYPE, ETH_CLK_MODE);

  if (MDNS.begin("esp32")) {
    Serial.println("MDNS responder started");
  }

  server.on("/", handleRoot);
  server.on("/test.svg", drawGraph);
  server.on("/inline", []() {
    server.send(200, "text/plain", "this works as well");
  });
  server.onNotFound(handleNotFound);
  server.begin();
  Serial.println("HTTP server started");
}

void loop(void) {
  server.handleClient();
}

void drawGraph() {
  String out = "";
  char temp[100];
  out += "<svg xmlns=\"http://www.w3.org/2000/svg\" version=\"1.1\" width=\"400\" height=\"150\">\n";
  out += "<rect width=\"400\" height=\"150\" fill=\"rgb(250, 230, 210)\" stroke-width=\"1\" stroke=\"rgb(0, 0, 0)\" />\n";
  out += "<g stroke=\"black\">\n";
  int y = rand() % 130;
  for (int x = 10; x < 390; x += 10) {
    int y2 = rand() % 130;
    sprintf(temp, "<line x1=\"%d\" y1=\"%d\" x2=\"%d\" y2=\"%d\" stroke-width=\"1\" />\n", x, 140 - y, x + 10, 140 - y2);
    out += temp;
    y = y2;
  }
  out += "</g>\n</svg>\n";

  server.send(200, "image/svg+xml", out);
}

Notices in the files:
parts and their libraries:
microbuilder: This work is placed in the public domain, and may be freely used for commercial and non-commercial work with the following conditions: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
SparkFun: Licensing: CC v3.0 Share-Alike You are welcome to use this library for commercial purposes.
